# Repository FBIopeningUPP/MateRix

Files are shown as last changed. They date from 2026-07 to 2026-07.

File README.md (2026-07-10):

# MateRix Cyberdeck

MateRix is a 10x10 LED Matrix console built around the ESP32-S3. It runs a standalone C++ operating system for embedded games (Tetris, Snake) and connects to a custom PyQt5 desktop application for live telemetry, screen painting, and device configuration over UART.

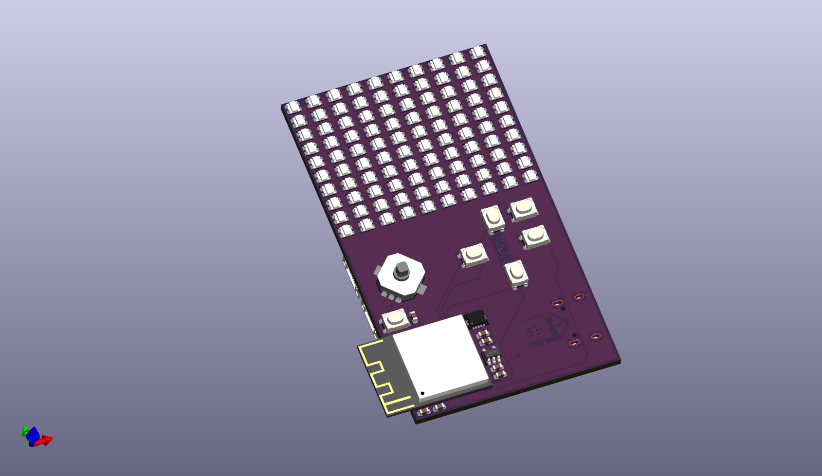
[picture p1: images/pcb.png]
Front PCB Render

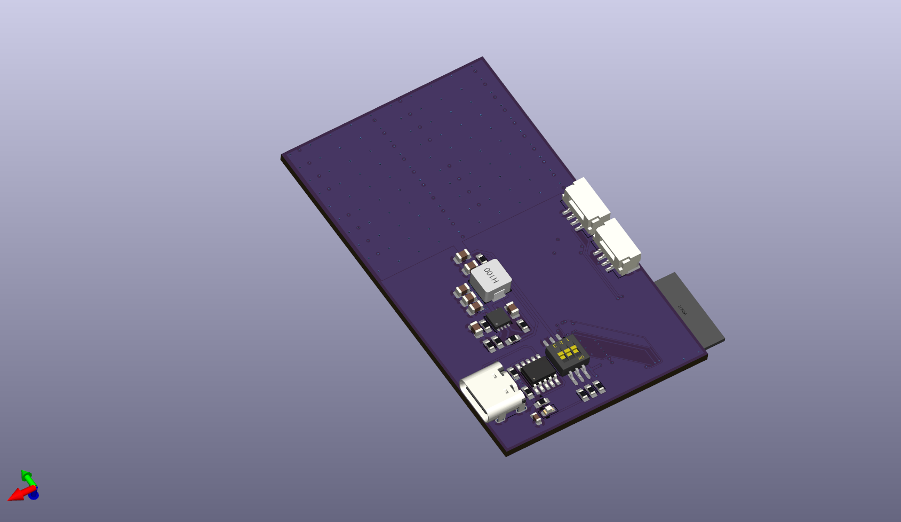
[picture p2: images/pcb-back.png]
Back PCB Render


## Features

* Standalone C++ embedded OS with multitasking state machine
* Playable Tetris and Snake game engines
* Hardware-level Matrix Digital Rain screensaver with idle timeout
* 10x10 WS2812B LED Matrix divided into 4 high-speed hardware quadrants
* Custom Python (PyQt5) desktop studio for live two-way UART communication
* Real-time telemetry broadcasting and remote device configuration
* Open-source hardware and firmware

## Hardware Specifications

* **MCU:** ESP32-S3-Mini
* **Display:** 100x WS2812B LEDs
* **Level Shifter:** 74AHCT125 (3.3V to 5V logic conversion)
* **Inputs:** 4-way D-Pad, 5 Action Buttons (A, B, X, Y, Start)

## Bill of Materials (BoM)

A complete, itemized BOM generated by KiCad can be viewed here: [Production](./production/bom.csv)

## Steps To Reproduce

### Hardware
1. The hardware design files are located in the `hardware/` directory. Send the Gerber files to a manufacturer to produce the PCB.
2. Solder the ESP32-S3-Mini, 74AHCT125, WS2812B LEDs, and tactile buttons.

### Firmware
1. Open the `firmware/` folder in VS Code using the PlatformIO extension.
2. Connect the ESP32-S3 via USB-C and upload the code.

### Software
1. Navigate to the `software/` folder.
2. Run the pre-compiled executable: `software\MateRix_Cyberdeck_Studio.exe`.
3. *(Optional)* To run from source, install dependencies with `pip install pyqt5 pyserial pyautogui` and run `python main.py`.

## Usage of AI

The usage of AI in this project was done with Google Antigravity, which acted as a pair programmer to help debug the C++ firmware, build the Python UI architecture, and verify the hardware pinouts and PCB routing strategies.

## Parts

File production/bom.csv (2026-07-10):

Designator | Footprint | Quantity | Value | LCSC Part #
C201, C203, C205 | 0603 | 3 | 100nF
C202, C204, C206, C207 | 0603 | 4 | 0.1uF
C401 | 0603 | 1 | 1uF
C501, C505 | 0805 | 2 | 100nF
C502, C503, C504 | 0805 | 3 | 1uF
C506, C507 | 0805 | 2 | 22uF
J201, J202 | JST_GH_SM04B-GHS-TB_1x04-1MP_P1.25mm_Horizontal | 2 | Conn_01x04_MountingPin
J401 | USB_C_Receptacle_GCT_USB4105-xx-A_16P_TopMnt_Horizontal | 1 | USB_C_Receptacle_USB2.0_16P
L501 | IND-SMD_L5.2-W5.2_MCW-0530 | 1 | SMMS0530-100M | C181721
LED301, LED302, LED303, LED304, LED305, LED306, LED307, LED308, LED309, LED310, LED311, LED312, LED313, LED314, LED315, LED316, LED317, LED318, LED319, LED320, LED321, LED322, LED323, LED324, LED325, LED326, LED327, LED328, LED329, LED330, LED331, LED332, LED333, LED334, LED335, LED336, LED337, LED338, LED339, LED340, LED341, LED342, LED343, LED344, LED345, LED346, LED347, LED348, LED349, LED350, LED351, LED352, LED353, LED354, LED355, LED356, LED357, LED358, LED359, LED360, LED361, LED362, LED363, LED364, LED365, LED366, LED367, LED368, LED369, LED370, LED371, LED372, LED373, LED374, LED375, LED376, LED377, LED378, LED379, LED380, LED381, LED382, LED383, LED384, LED385, LED386, LED387, LED388, LED389, LED390, LED391, LED392, LED393, LED394, LED395, LED396, LED397, LED398, LED399, LED400 | LED-SMD_4P-L2.0-W2.0-TL_WS2812B-2020 | 100 | WS2812B | C965555
LED401 | 0603 | 1 | LED_0603
R401, R404, R405, R406 | R_0603 | 4 | 10k
R402, R403 | R_0603 | 2 | 1k
R501 | R_0603 | 1 | 100k
R502 | R_0603 | 1 | 330k
R503 | R_0603 | 1 | 20
R504 | R_0603 | 1 | 41.2k
R505 | R_0603 | 1 | 51k
R506 | R_0603 | 1 | 6.98k
SW201 | SW-SMD_SKRHAAE010 | 1 | SKRHAAE010 | C202423
SW202, SW203, SW204, SW205, SW206, SW207 | KEY-SMD_4P-L4.2-W3.2-P2.20-LS4.6 | 6 | SKRPABE010 | C115360
SW401 | SW-SMD_DSHP03TS-S | 1 | DSHP03TS-S | C319051
U202 | DHVQFN-14_L3.0-W2.5-P0.50-BL-EP | 1 | 74AHCT125BQ,115 | C554499
U203 | SOT-23-5_L3.0-W1.7-P0.95-LS2.8-TL | 1 | MIC5219-3.3YM5 | C29613
U401 | SSOP-10-1EP_3.9x4.9mm_P1mm_EP2.1x3.3mm_ThermalVias | 1 | CH224K
U402 | BULETM-SMD_ESP32-S3-MINI-1-N8 | 1 | ESP32-S3-MINI-1-N8 | C2913206
U501 | QFN-8_L3.0-W3.0-P0.65-BL | 1 | MP9943GQ | C51889390

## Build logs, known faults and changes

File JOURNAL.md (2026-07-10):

---
title: MateRix
author: Milind Singh
description: MateRix a esp32 s3 and ws2812b 2020 10x10 matrix display with joystick and some buttons for fun
created_at: 2026-07-20
---

### Total time spent: 
## July 10th -

Today morning i started this simple project with something fun in mind
i choose to build a rgb matrix with joystick and esp32 and some buttons
i wrote the c++ and python code where the mcu is programmed with 2 games and pc mode and screen saver
pc mode u can interact with the python app

the whole project was easy and fast so i completed it fast so i can go to horizons

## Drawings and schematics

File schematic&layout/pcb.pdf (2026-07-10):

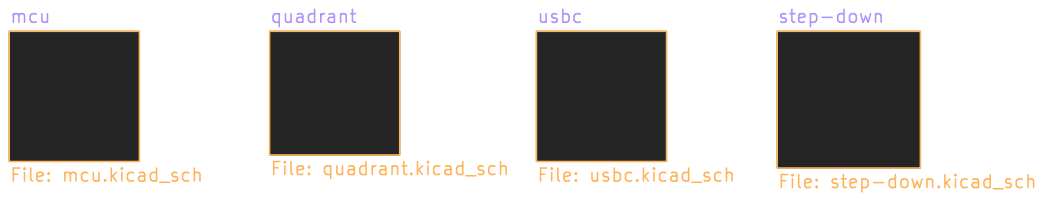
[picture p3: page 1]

step-down File: step-down.kicad_sch

Id: 1/5 Title: File: pcb.kicad_sch Sheet: /

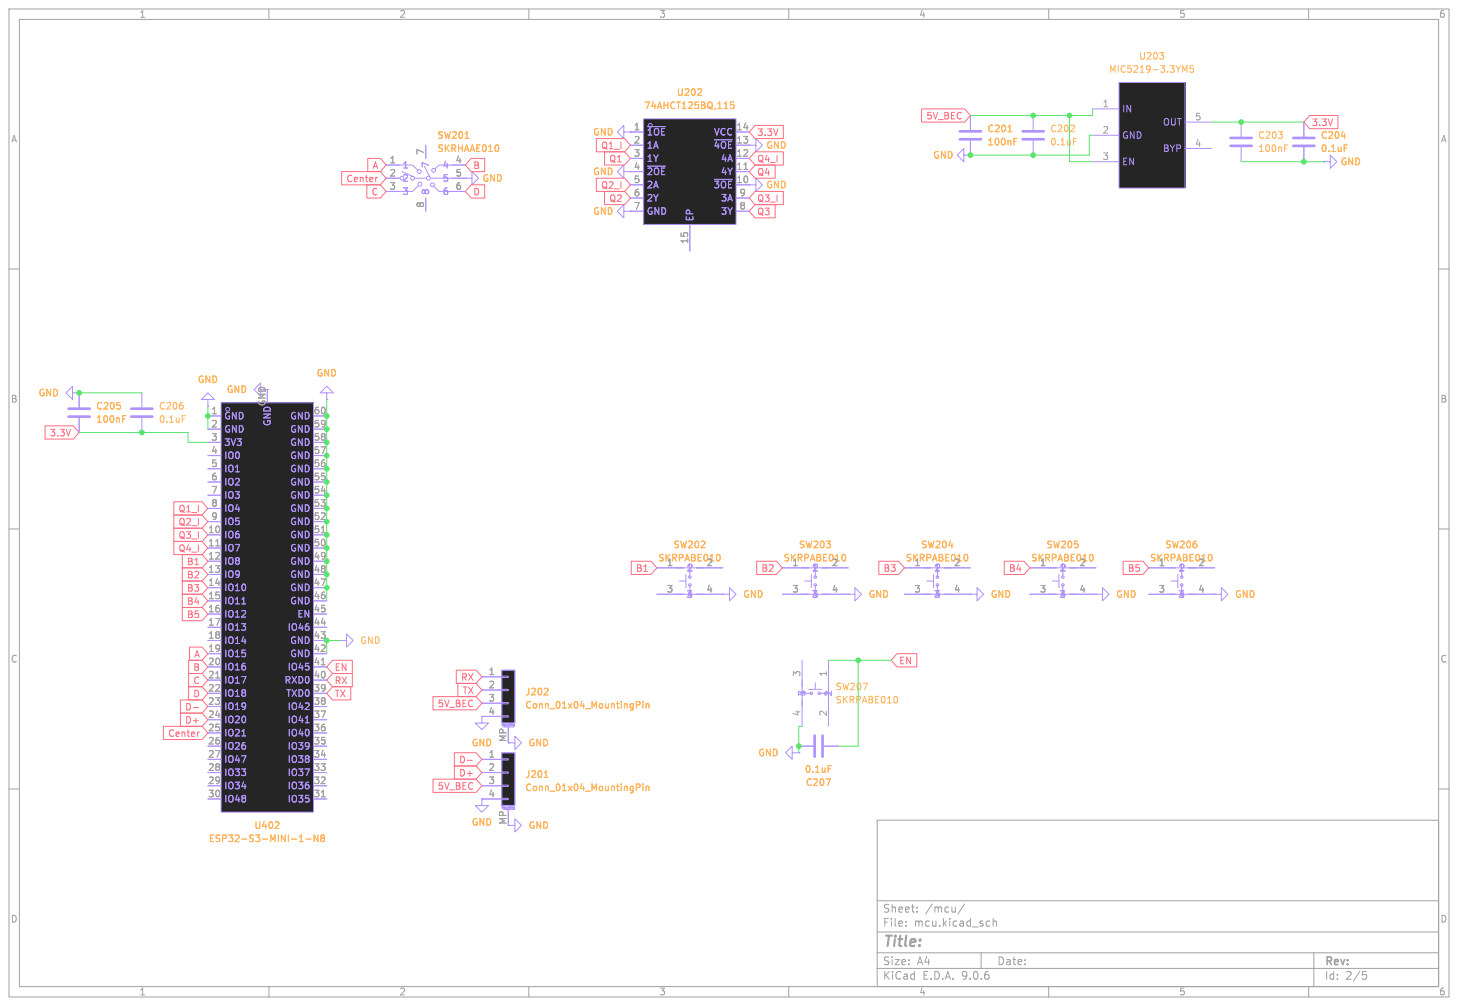
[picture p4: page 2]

Id: 2/5 Title: File: mcu.kicad_sch Sheet: /mcu/ 1

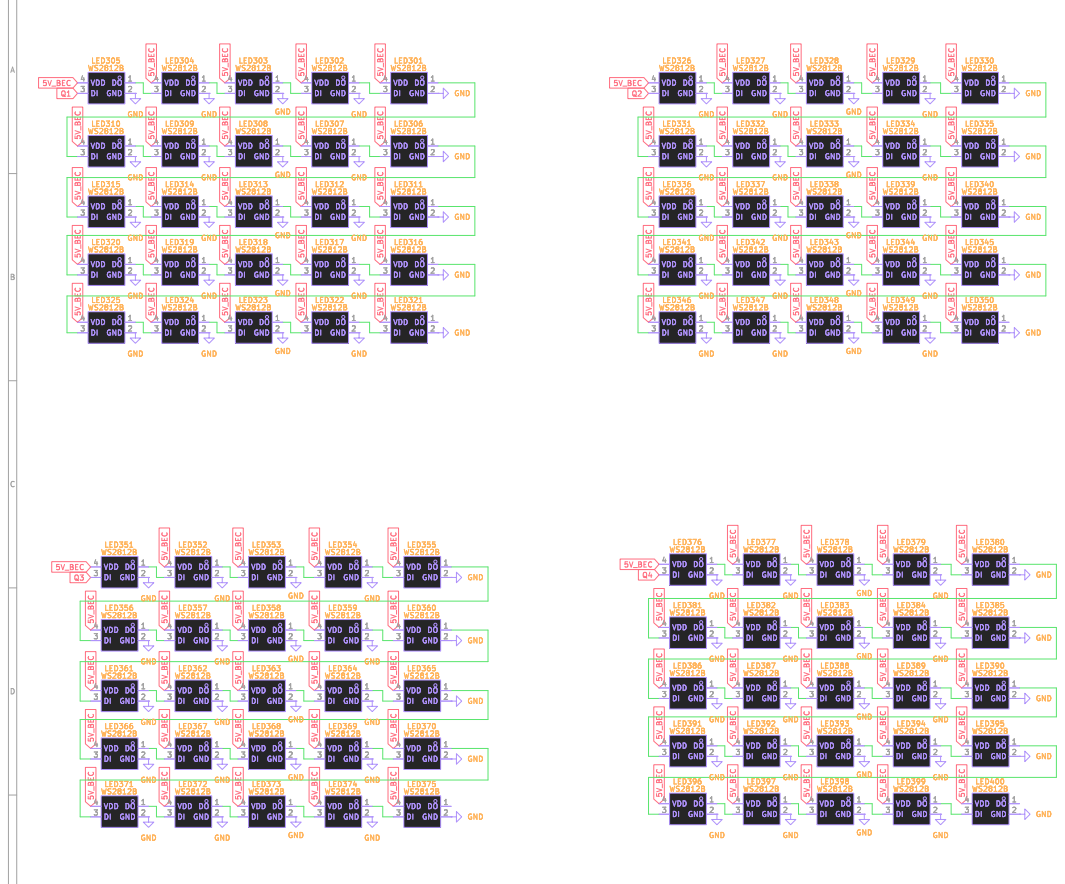
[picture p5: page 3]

LED302 WS2812BDO 1 GND 2 VDD 4 DI 3 GND

LED301 WS2812BDO 1 GND 2 VDD 4 DI 3 GND

LED327 WS2812B DO 1 GND 2 VDD 4 DI 3

DO 1 GND 2 VDD 4 DI 3

LED335 WS2812B DO 1 GND 2 VDD 4 DI 3

LED312 WS2812B DO 1 GND 2 VDD 4 DI 3

LED318 WS2812BDO 1 GND 2 VDD 4 DI 3 GND GND

LED345 WS2812BDO 1 GND 2 VDD 4 DI 3 GND LED344 WS2812BDO 1 GND 2 VDD 4 DI 3

LED344 WS2812B DO 1 GND 2 VDD 4 DI 3

LED359 WS2812B DO 1 GND 2 VDD 4 DI 3

LED376 WS2812B DO 1 GND 2 VDD 4 DI 3

LED350 WS2812BDO 1 GND 2 VDD 4 DI 3 GND
LED348 WS2812BDO 1 GND 2 VDD 4 DI 3 GND

LED322 WS2812B DO 1 GND 2 VDD 4 DI 3

LED347 WS2812B DO 1 GND 2 VDD 4 DI 3

LED352 WS2812B GND

LED380 WS2812BDO 1 GND 2 VDD 4 DI 3 GND

LED359 WS2812BDO 1 GND 2 VDD 4 DI 3 GND

LED390 WS2812BDO 1 GND 2 VDD 4 DI 3 GND

LED385 WS2812BDO 1 GND 2 VDD 4 DI 3 GND

LED389 WS2812B DO 1 GND 2 VDD 4 DI 3

LED395 WS2812B DO 1 GND 2 VDD 4 DI 3

LED373 WS2812B DO 1 GND 2 VDD 4 DI 3

LED375 WS2812BDO 1 GND 2 VDD 4 DI 3 GND

Id: 3/5 Title: File: quadrant.kicad_sch Sheet: /quadrant/

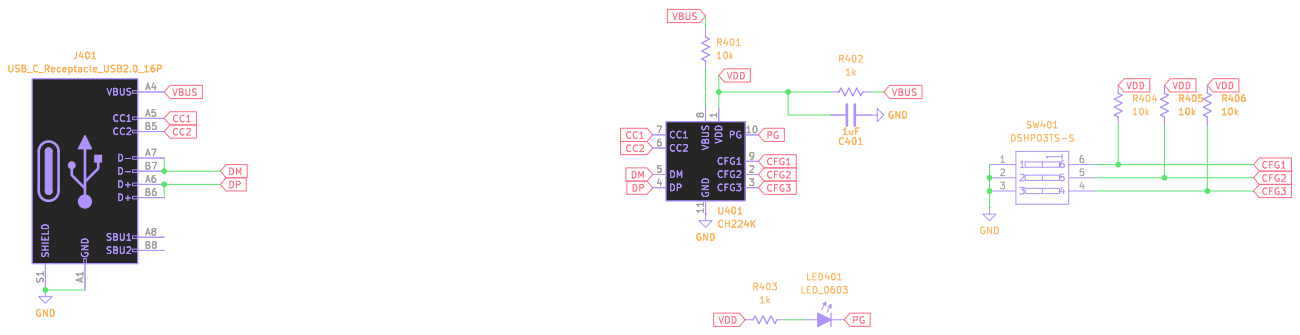
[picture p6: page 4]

Id: 4/5 Title: File: usbc.kicad_sch Sheet: /usbc/ GND

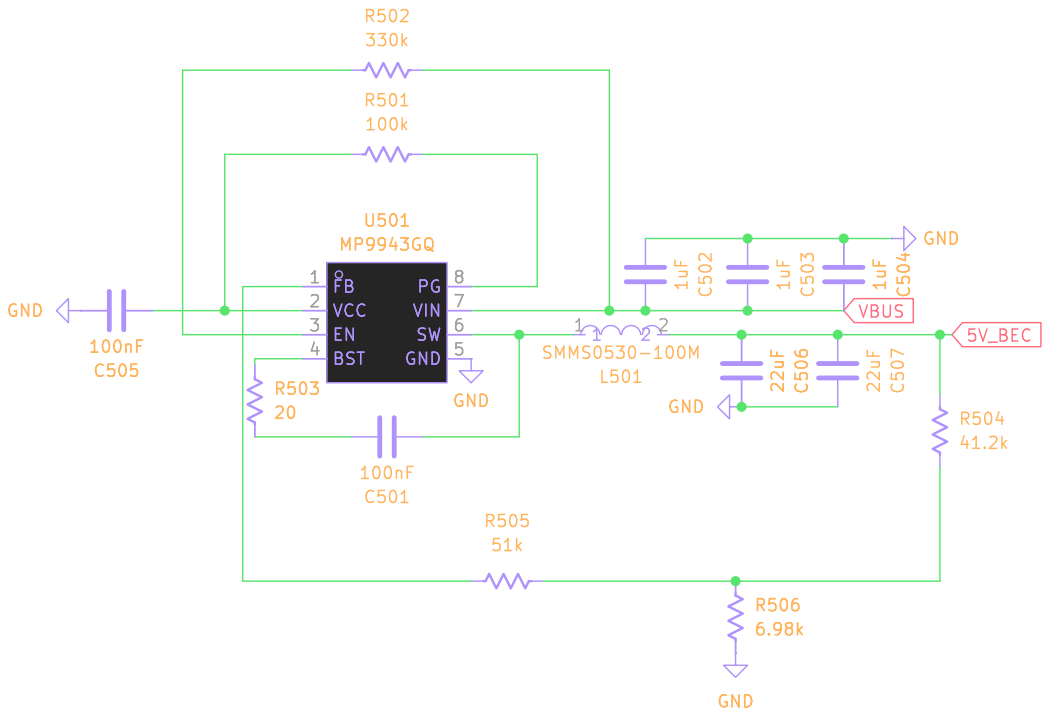
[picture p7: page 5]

Id: 5/5 Title: File: step-down.kicad_sch Sheet: /step-down/

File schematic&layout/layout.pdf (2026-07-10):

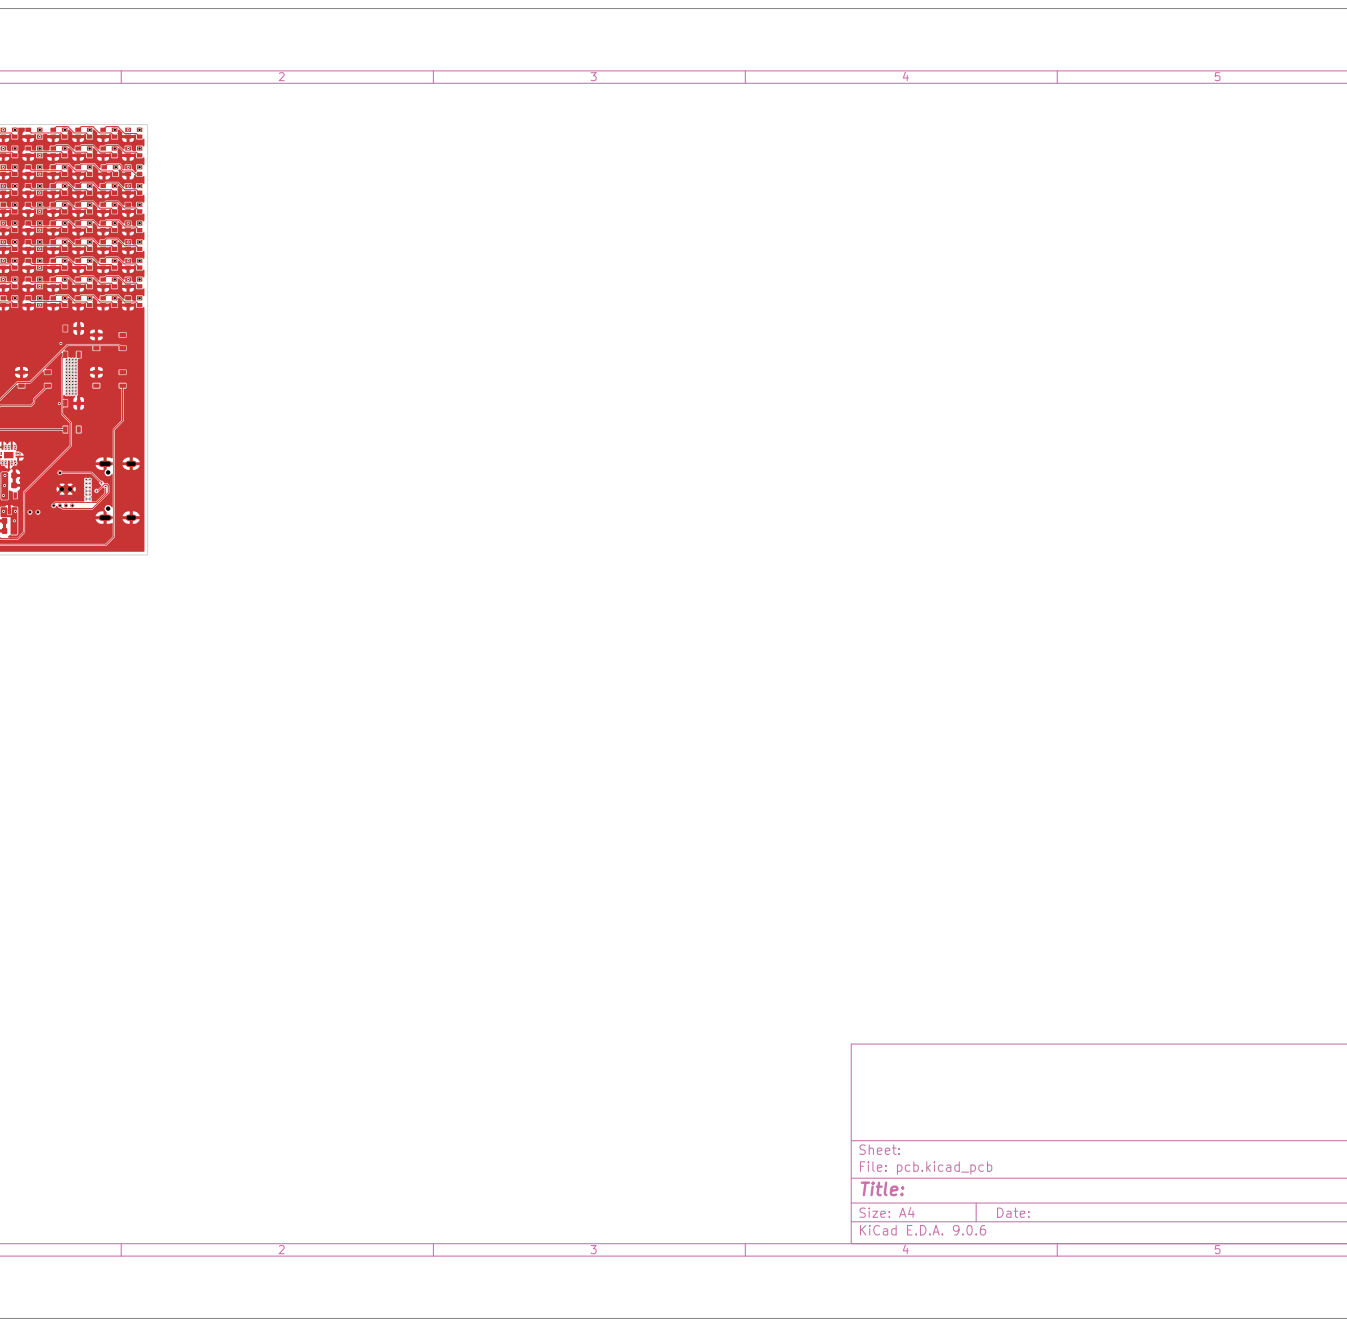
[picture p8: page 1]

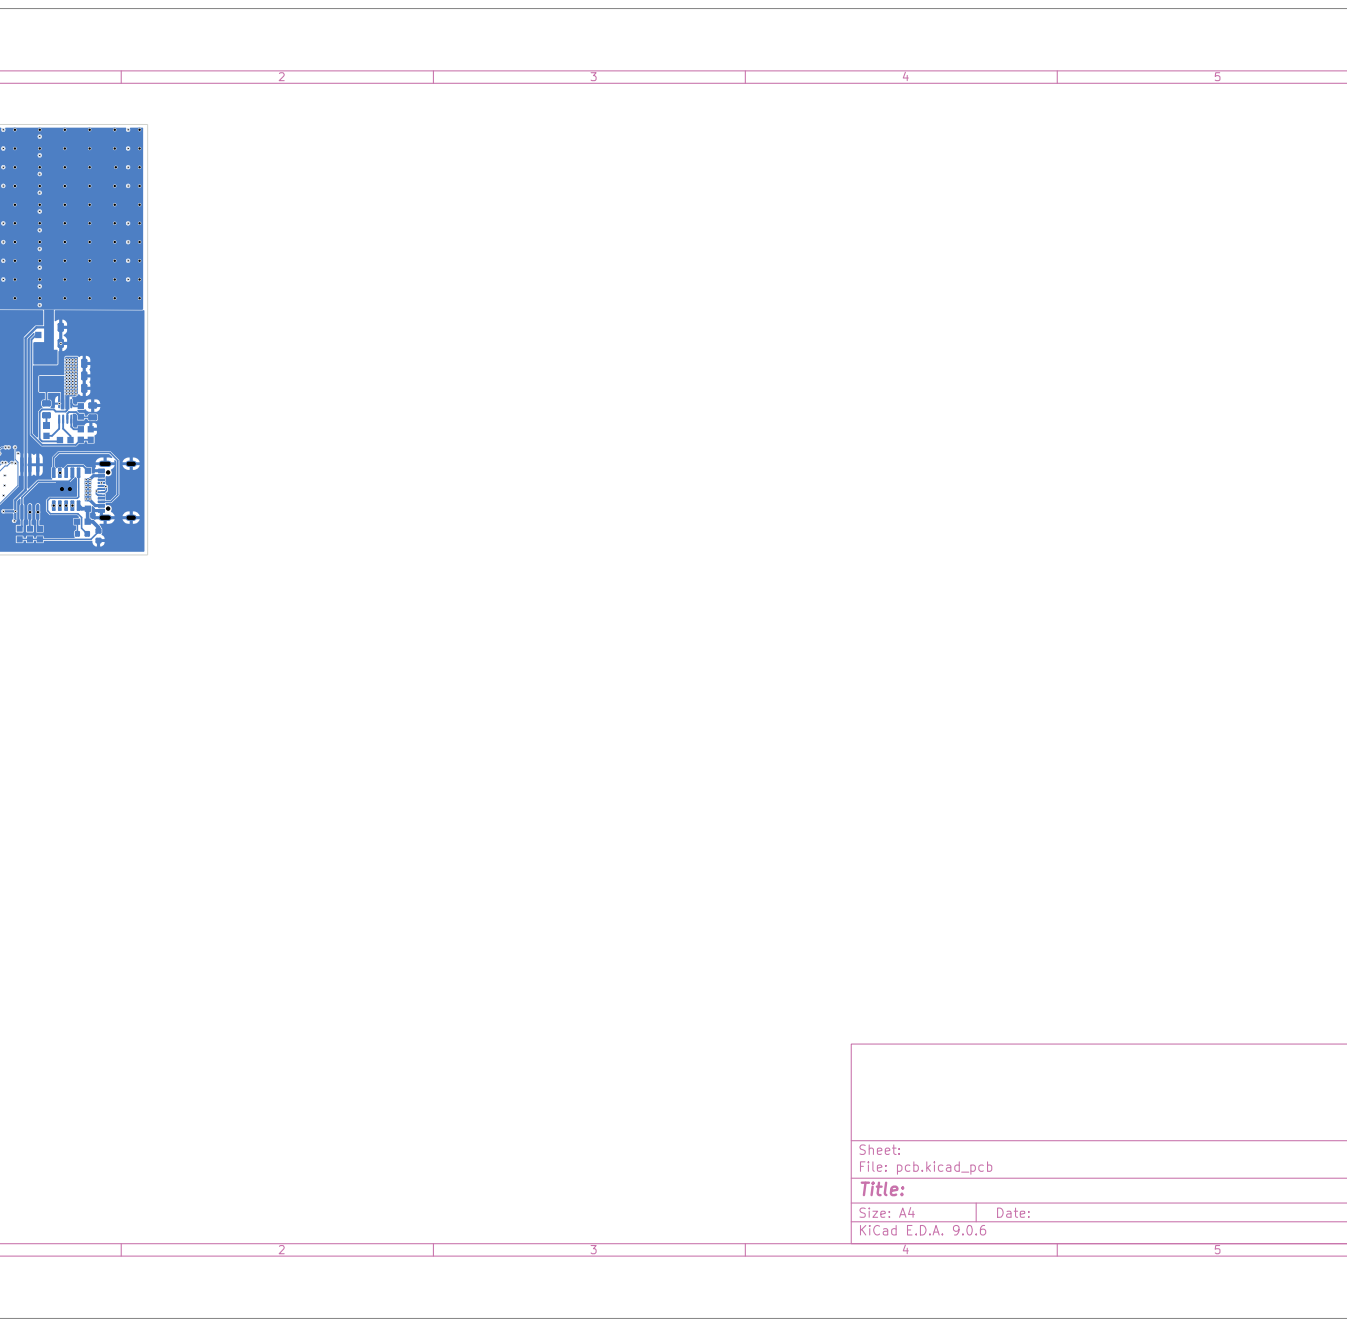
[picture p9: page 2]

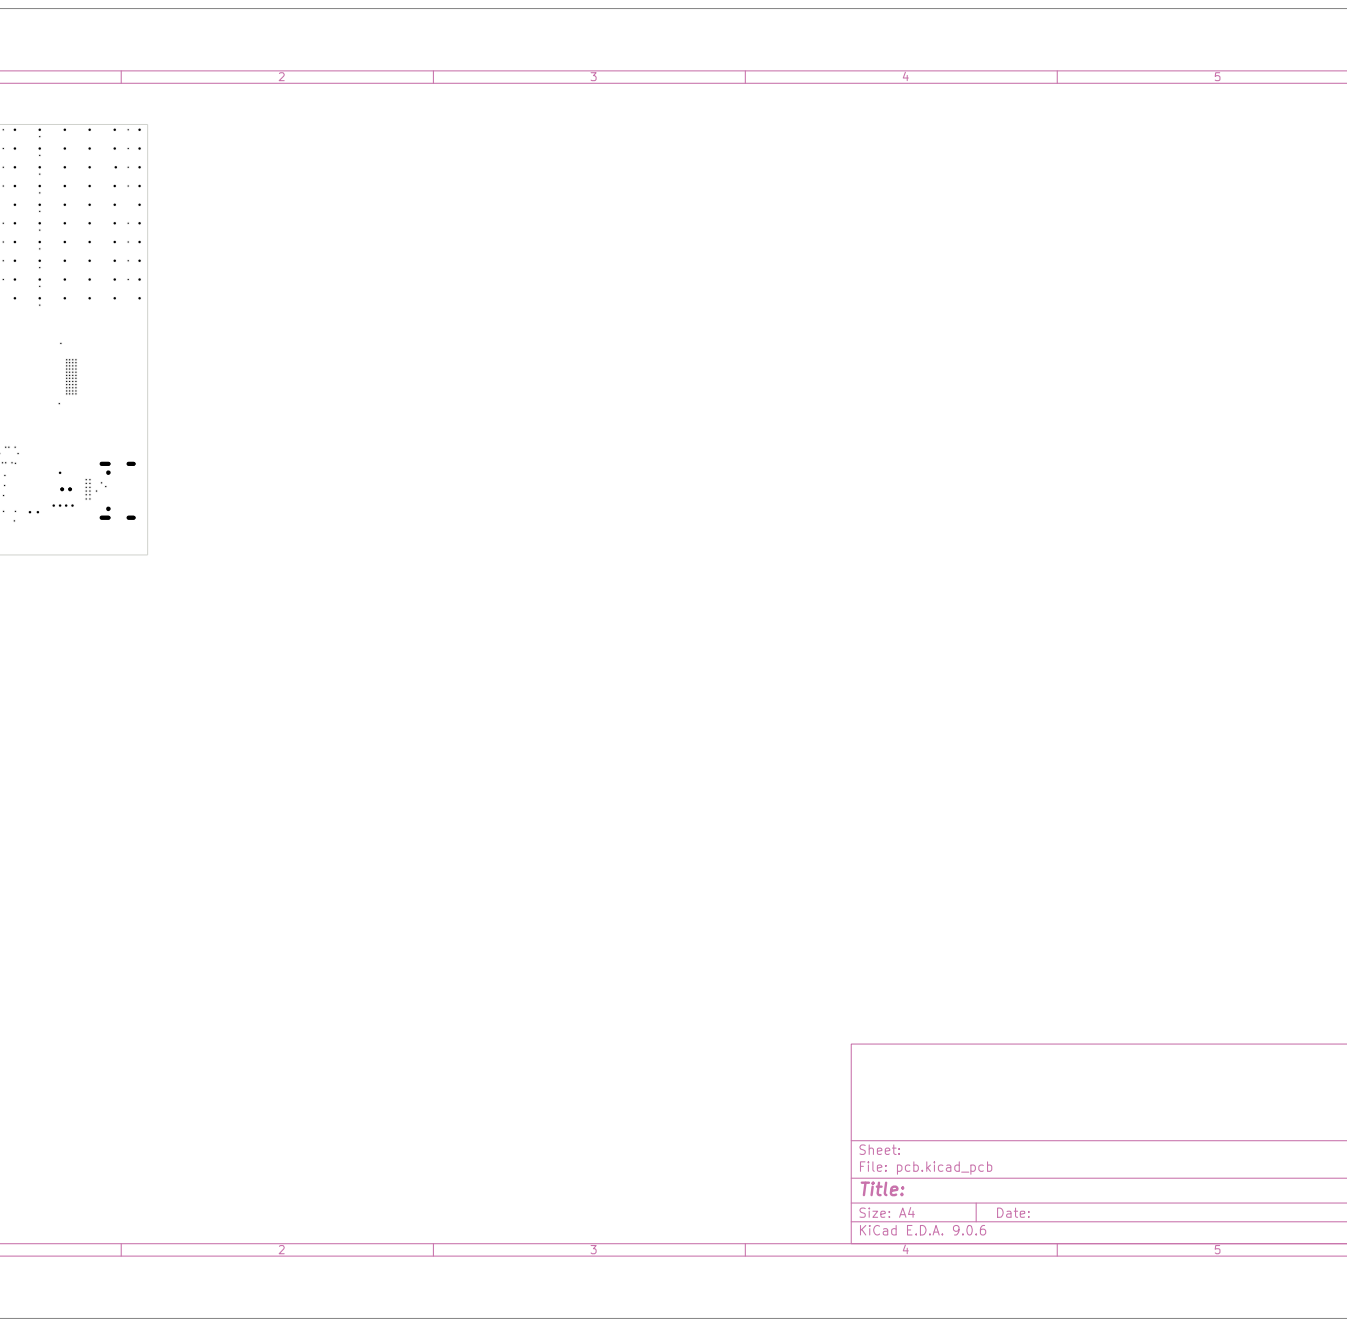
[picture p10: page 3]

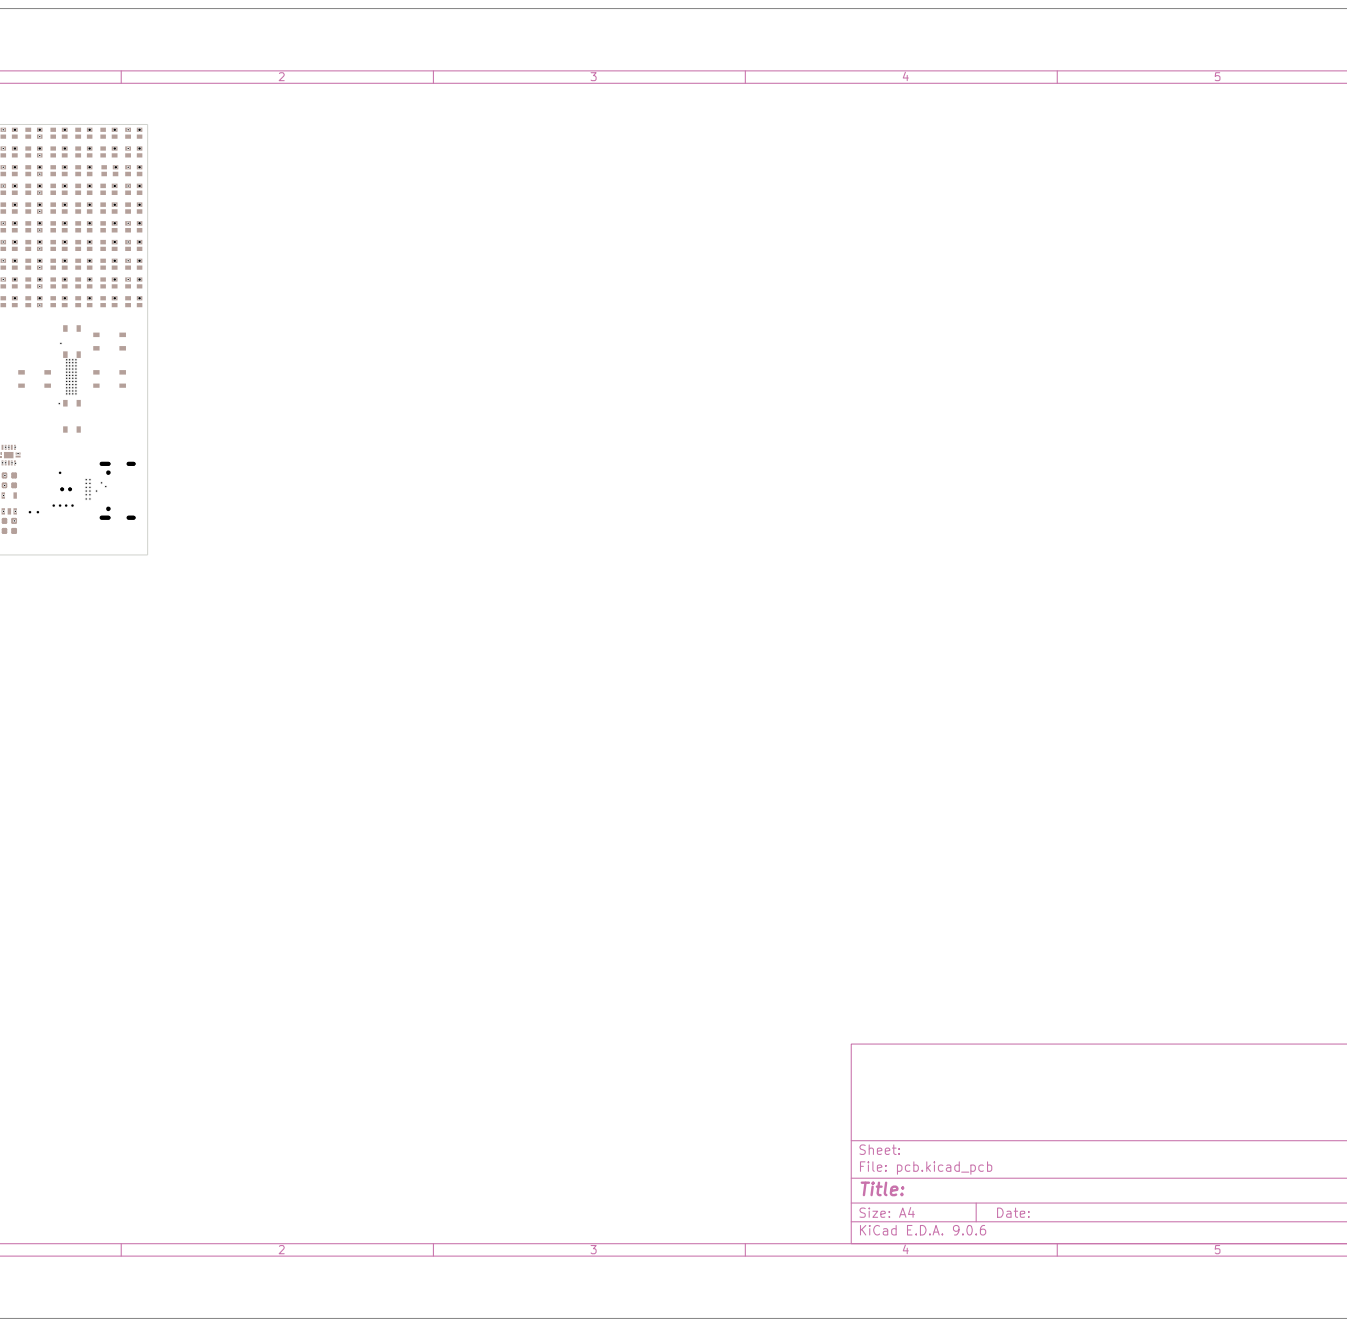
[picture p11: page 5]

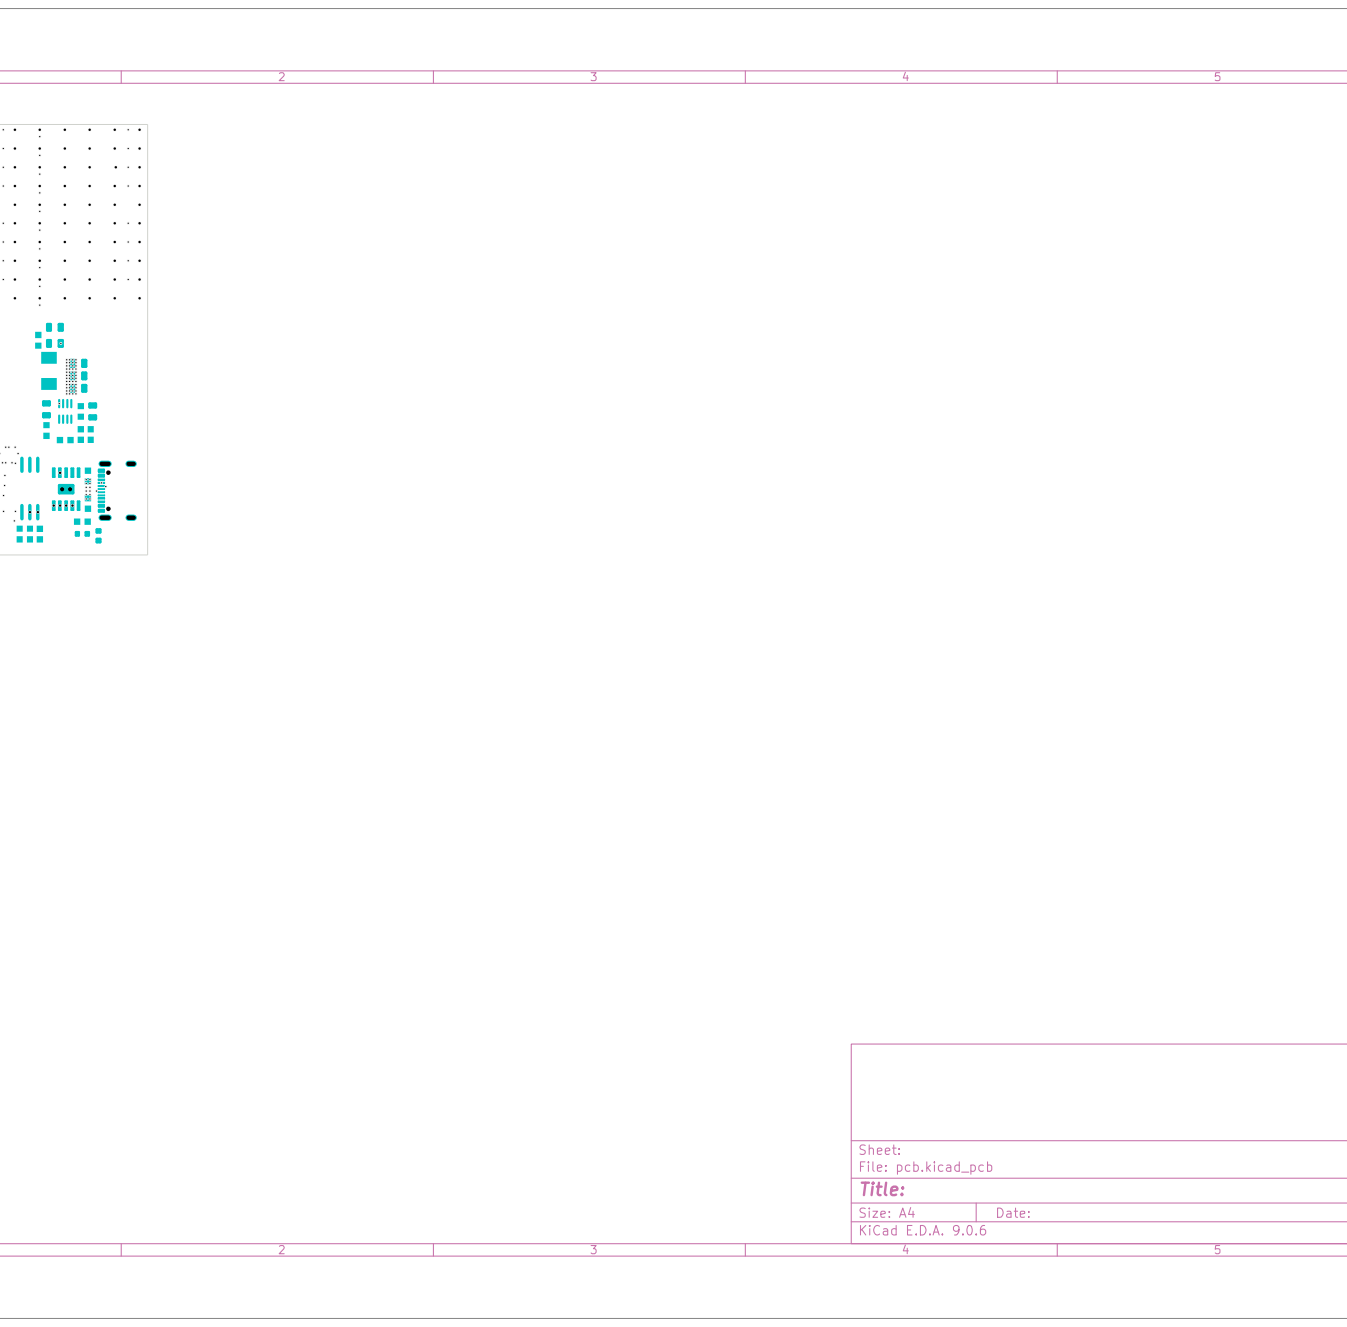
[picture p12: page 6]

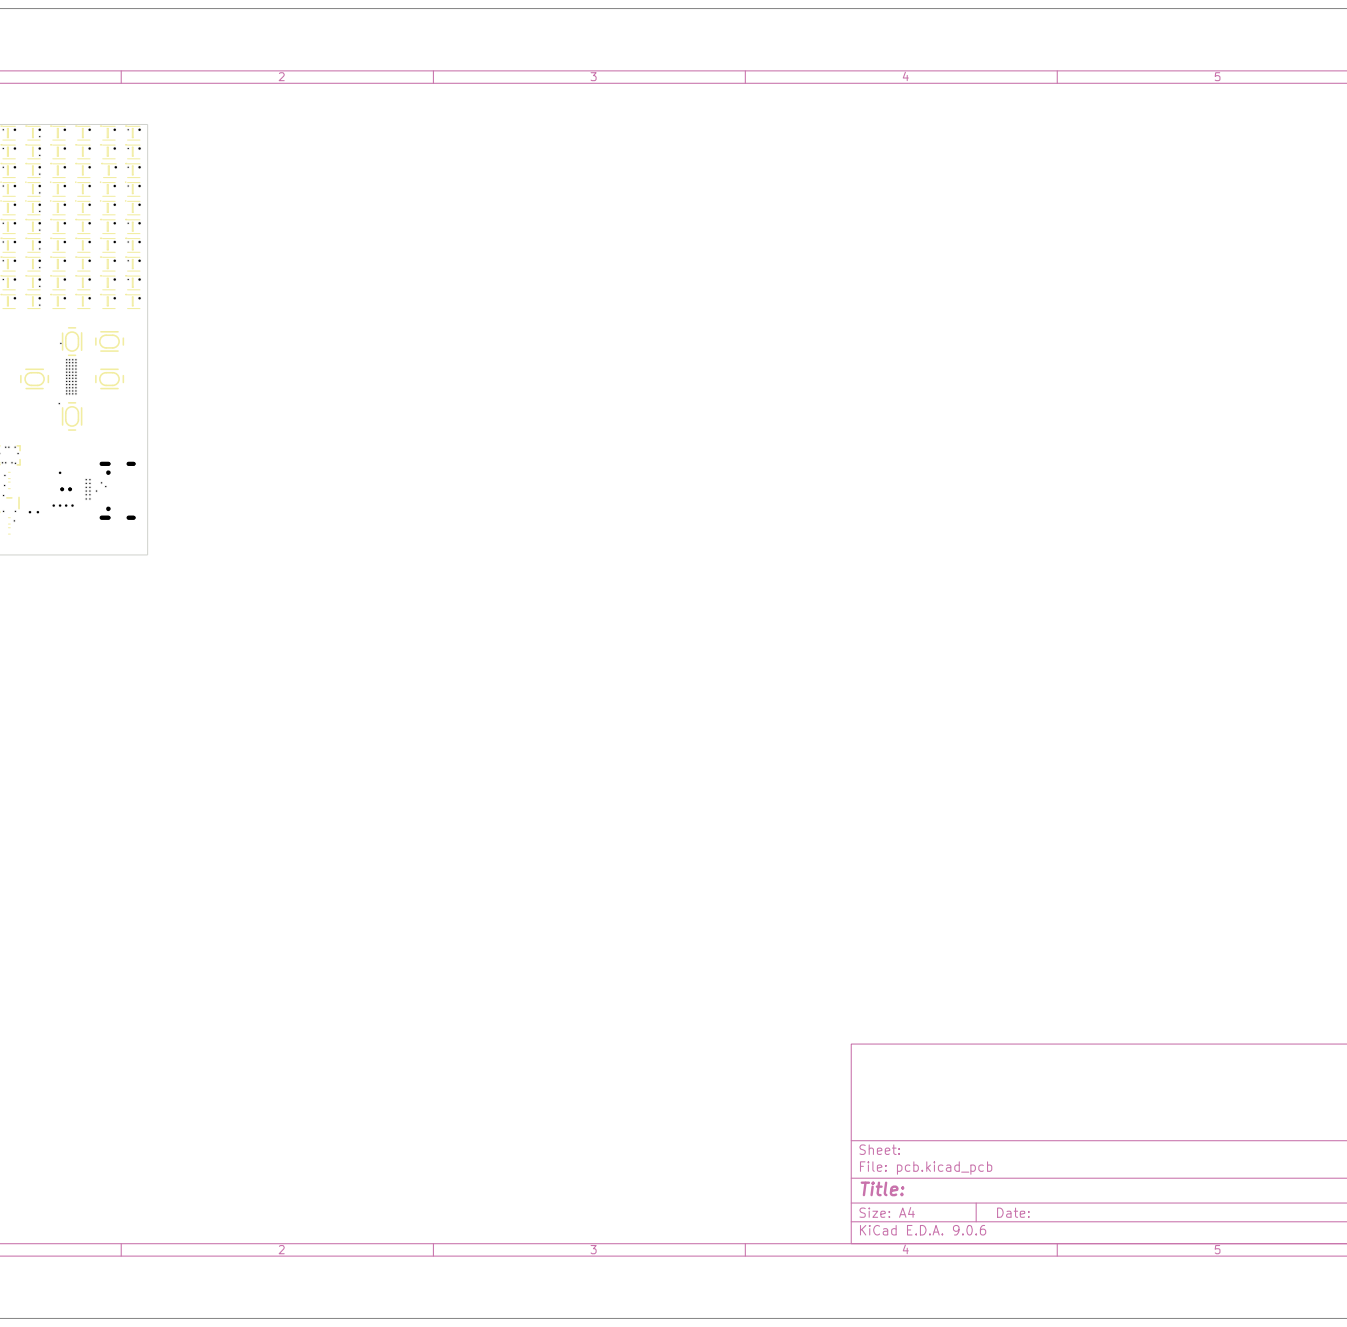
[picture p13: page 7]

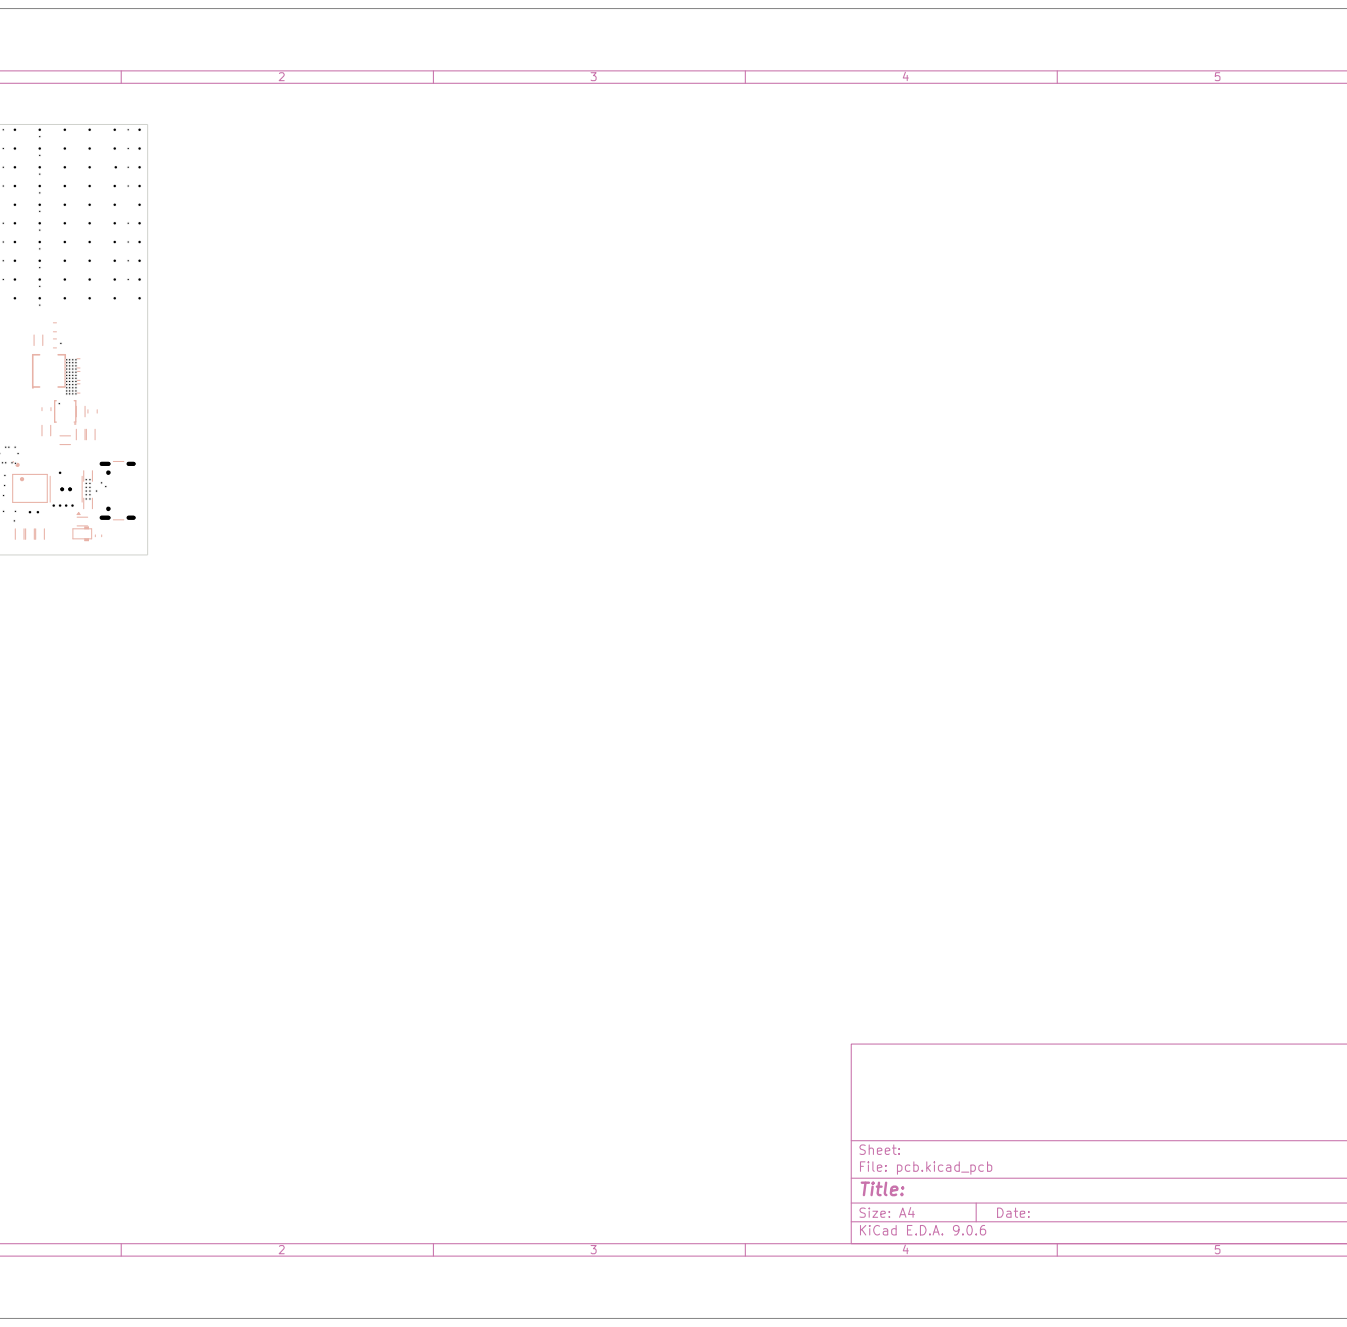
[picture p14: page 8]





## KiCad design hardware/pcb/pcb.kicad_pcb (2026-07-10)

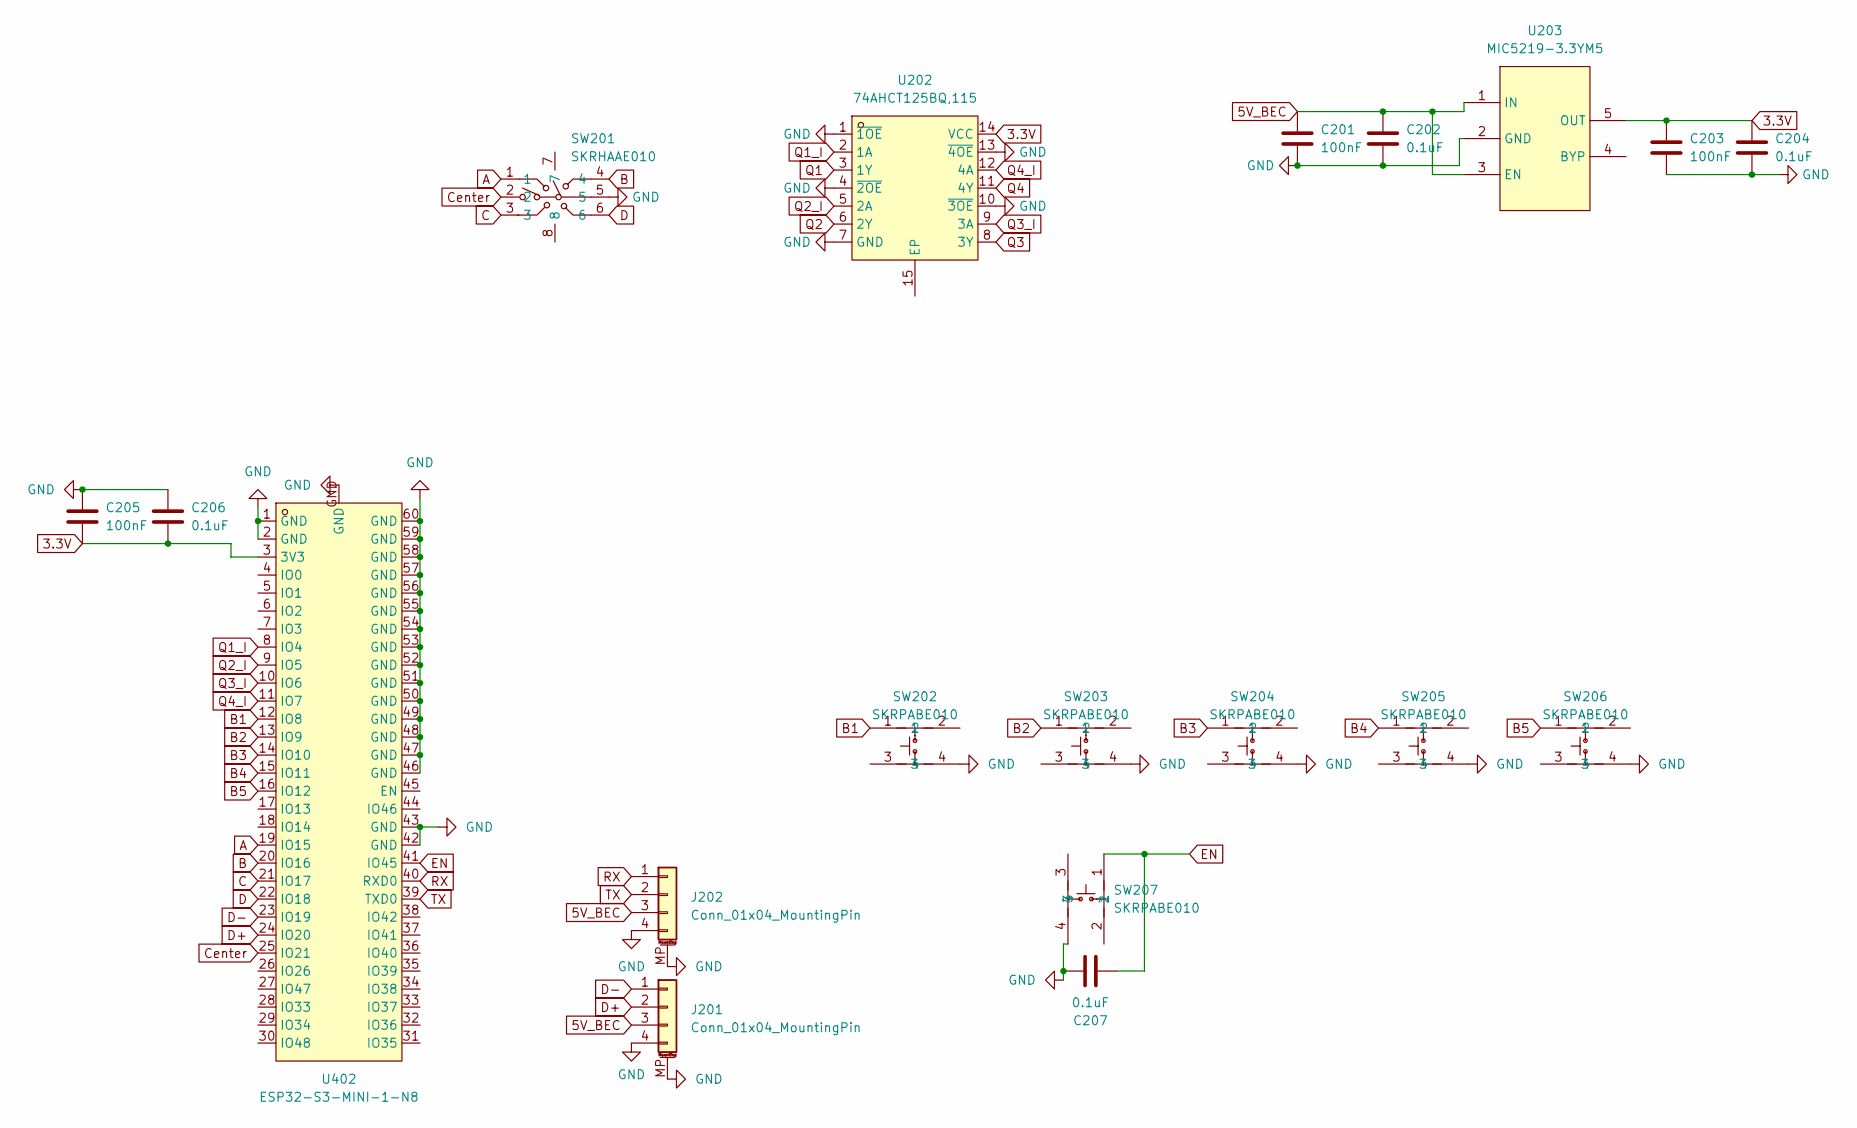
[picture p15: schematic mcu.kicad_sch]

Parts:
C201, C203, C205: 100nF; C_0603_1608Metric
C202, C204, C206, C207: 0.1uF; C_0603_1608Metric
J201, J202: Conn_01x04_MountingPin; JST_GH_SM04B-GHS-TB_1x04-1MP_P1.25mm_Horizontal
SW201: SKRHAAE010; SW-SMD_SKRHAAE010; MPN SKRHAAE010; LCSC Part C202423
SW202, SW203, SW204, SW205, SW206, SW207: SKRPABE010; KEY-SMD_4P-L4.2-W3.2-P2.20-LS4.6; LCSC Part C115360
U202: 74AHCT125BQ,115; DHVQFN-14_L3.0-W2.5-P0.50-BL-EP; MPN 74AHCT125BQ,115; LCSC Part C554499
U203: MIC5219-3.3YM5; SOT-23-5_L3.0-W1.7-P0.95-LS2.8-TL; LCSC Part C29613
U402: ESP32-S3-MINI-1-N8; BULETM-SMD_ESP32-S3-MINI-1-N8; MPN ESP32-S3-MINI-1-N8; LCSC Part C2913206

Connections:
3.3V: C203.1, C204.1, C205.2, C206.2, U202.14 (VCC), U203.5 (OUT), U402.3 (3V3)
5V_BEC: C201.1, C202.1, J201.3, J202.3, U203.1 (IN), U203.3 (EN); also elsewhere on the board
A: SW201.1, U402.19 (IO15)
B: SW201.4, U402.20 (IO16)
B1: SW202.1, U402.12 (IO8)
B2: SW203.1, U402.13 (IO9)
B3: SW204.1, U402.14 (IO10)
B4: SW205.1, U402.15 (IO11)
B5: SW206.1, U402.16 (IO12)
C: SW201.3, U402.21 (IO17)
Center: SW201.2, U402.25 (IO21)
D: SW201.6, U402.22 (IO18)
D+: J201.2, U402.24 (IO20)
D-: J201.1, U402.23 (IO19)
EN: C207.2, SW207.1, U402.41 (IO45)
GND: C201.2, C202.2, C203.2, C204.2, C205.1, C206.1, C207.1, J201.4, J201.MP (MountPin), J202.4, J202.MP (MountPin), SW201.5, SW202.4, SW203.4, SW204.4, SW205.4, SW206.4, SW207.4, U202.1 (~1OE), U202.4 (~2OE), U202.7 (GND), U202.10 (~3OE), U202.13 (~4OE), U203.2 (GND), U402.1 (GND), U402.2 (GND), U402.42 (GND), U402.43 (GND), U402.46 (GND), U402.47 (GND), U402.48 (GND), U402.49 (GND), U402.50 (GND), U402.51 (GND), U402.52 (GND), U402.53 (GND), U402.54 (GND), U402.55 (GND), U402.56 (GND), U402.57 (GND), U402.58 (GND), U402.59 (GND), U402.60 (GND), U402.GND; also elsewhere on the board
Q1: U202.3 (1Y); also elsewhere on the board
Q1_I: U202.2 (1A), U402.8 (IO4)
Q2: U202.6 (2Y); also elsewhere on the board
Q2_I: U202.5 (2A), U402.9 (IO5)
Q3: U202.8 (3Y); also elsewhere on the board
Q3_I: U202.9 (3A), U402.10 (IO6)
Q4: U202.11 (4Y); also elsewhere on the board
Q4_I: U202.12 (4A), U402.11 (IO7)
RX: J202.1, U402.40 (RXD0)
TX: J202.2, U402.39 (TXD0)

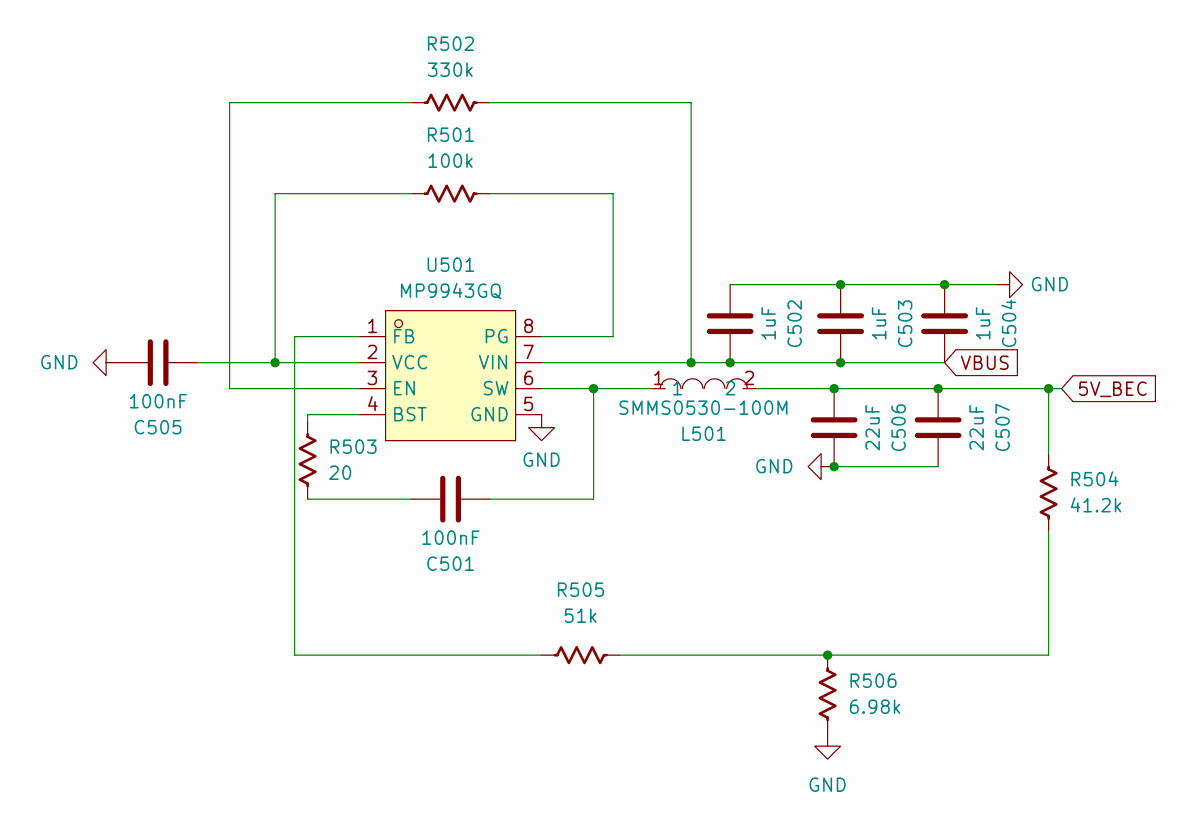
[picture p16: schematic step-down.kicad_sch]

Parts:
C501, C505: 100nF; C_0805_2012Metric
C502, C503, C504: 1uF; C_0805_2012Metric
C506, C507: 22uF; C_0805_2012Metric
L501: SMMS0530-100M; IND-SMD_L5.2-W5.2_MCW-0530; MPN SMMS0530-100M; LCSC Part C181721
R501: 100k; R_0603
R502: 330k; R_0603
R503: 20; R_0603
R504: 41.2k; R_0603
R505: 51k; R_0603
R506: 6.98k; R_0603
U501: MP9943GQ; QFN-8_L3.0-W3.0-P0.65-BL; MPN MP9943GQ(TOKMAS); LCSC Part C51889390

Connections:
5V_BEC: C506.2, C507.2, L501.2, R504.2; also elsewhere on the board
GND: C502.2, C503.2, C504.2, C505.1, C506.1, C507.1, R506.2, U501.5 (GND); also elsewhere on the board
unnamed: C501.1, R503.2
unnamed: R504.1, R505.1, R506.1
unnamed: R503.1, U501.4 (BST)
unnamed: R502.2, U501.3 (EN)
unnamed: R505.2, U501.1 (FB)
unnamed: R501.1, U501.8 (PG)
unnamed: C501.2, L501.1, U501.6 (SW)
unnamed: C505.2, R501.2, U501.2 (VCC)
VBUS: C502.1, C503.1, C504.1, R502.1, U501.7 (VIN); also elsewhere on the board

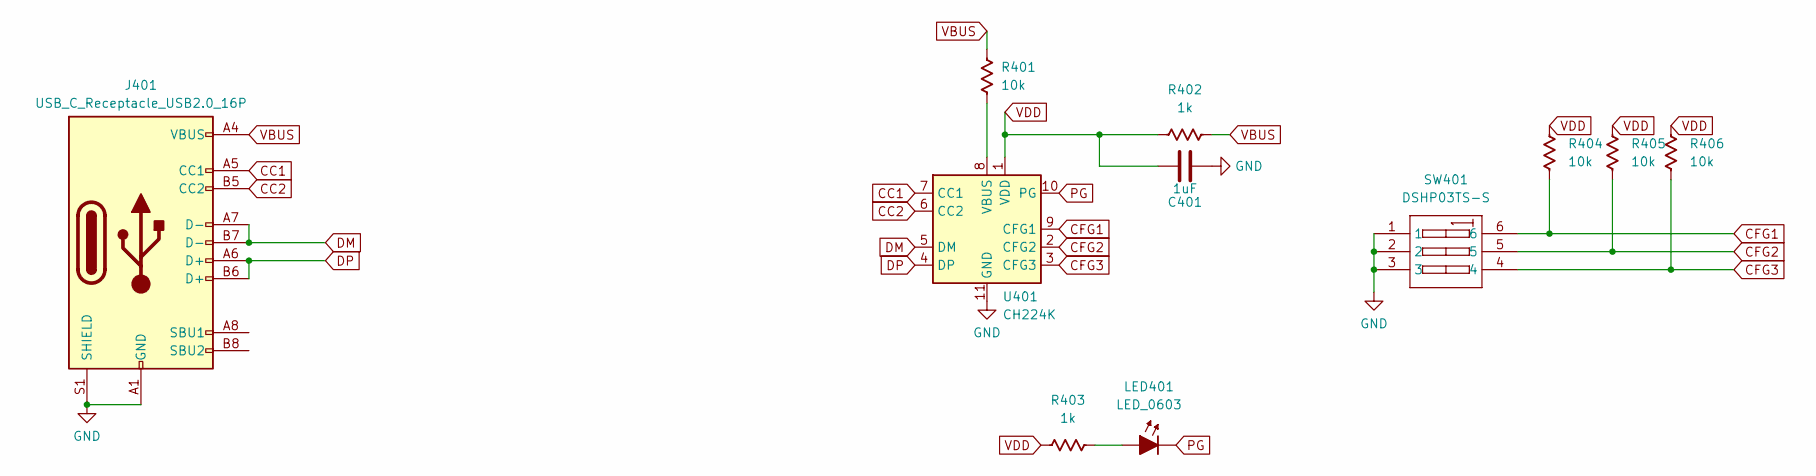
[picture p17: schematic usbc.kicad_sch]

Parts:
C401: 1uF; C_0603_1608Metric
J401: USB_C_Receptacle_USB2.0_16P; USB_C_Receptacle_GCT_USB4105-xx-A_16P_TopMnt_Horizontal
LED401: LED_0603; LED_0603_1608Metric
R401, R404, R405, R406: 10k; R_0603
R402, R403: 1k; R_0603
SW401: DSHP03TS-S; SW-SMD_DSHP03TS-S; MPN DSHP03TS-S; LCSC Part C319051
U401: CH224K; SSOP-10-1EP_3.9x4.9mm_P1mm_EP2.1x3.3mm_ThermalVias

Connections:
CC1: J401.A5 (CC1), U401.7 (CC1)
CC2: J401.B5 (CC2), U401.6 (CC2)
CFG1: R404.1, SW401.6, U401.9 (CFG1)
CFG2: R405.1, SW401.5, U401.2 (CFG2)
CFG3: R406.1, SW401.4, U401.3 (CFG3)
DM: J401.A7 (D-), J401.B7 (D-), U401.5 (DM)
DP: J401.A6 (D+), J401.B6 (D+), U401.4 (DP)
GND: C401.2, J401.A1 (GND), J401.A12 (GND), J401.B1 (GND), J401.B12 (GND), J401.S1 (SHIELD), SW401.1, SW401.2, SW401.3, U401.11 (GND); also elsewhere on the board
unnamed: LED401.2 (A), R403.2
unnamed: R401.2, U401.8 (VBUS)
PG: LED401.1 (K), U401.10 (PG)
VBUS: J401.A4 (VBUS), J401.A9 (VBUS), J401.B4 (VBUS), J401.B9 (VBUS), R401.1, R402.2; also elsewhere on the board
VDD: C401.1, R402.1, R403.1, R404.2, R405.2, R406.2, U401.1 (VDD)

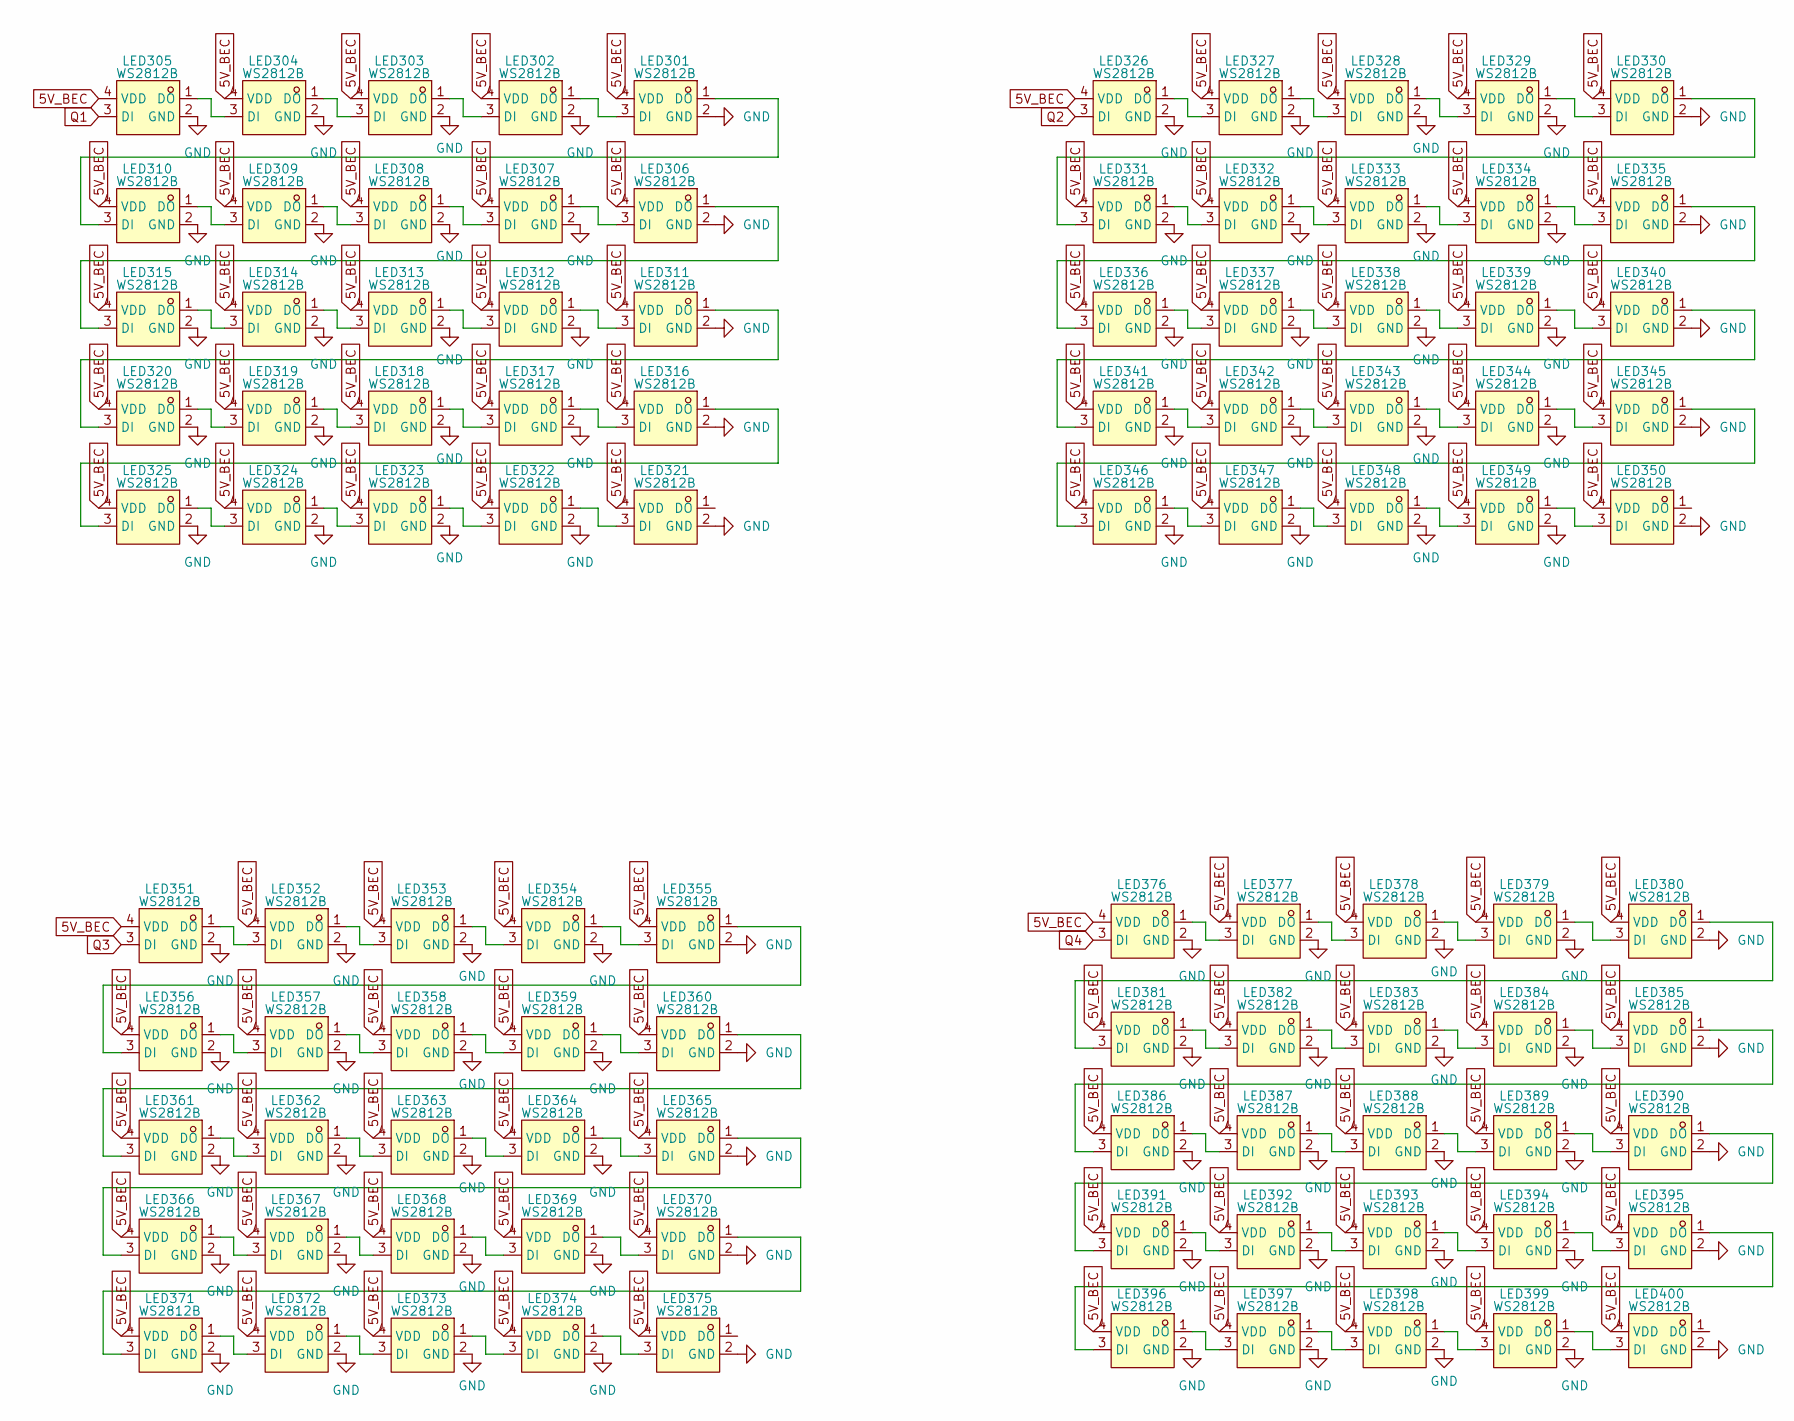
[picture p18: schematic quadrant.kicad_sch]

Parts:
LED301, LED302, LED303, LED304, LED305, LED306, LED307, LED308, LED309, LED310, LED311, LED312, LED313, LED314, LED315, LED316, LED317, LED318, LED319, LED320, LED321, LED322, LED323, LED324, LED325, LED326, LED327, LED328, LED329, LED330, LED331, LED332, LED333, LED334, LED335, LED336, LED337, LED338, LED339, LED340, LED341, LED342, LED343, LED344, LED345, LED346, LED347, LED348, LED349, LED350, LED351, LED352, LED353, LED354, LED355, LED356, LED357, LED358, LED359, LED360, LED361, LED362, LED363, LED364, LED365, LED366, LED367, LED368, LED369, LED370, LED371, LED372, LED373, LED374, LED375, LED376, LED377, LED378, LED379, LED380, LED381, LED382, LED383, LED384, LED385, LED386, LED387, LED388, LED389, LED390, LED391, LED392, LED393, LED394, LED395, LED396, LED397, LED398, LED399, LED400: WS2812B; LED-SMD_4P-L2.0-W2.0-TL_WS2812B-2020; MPN WS2812B-2020; LCSC Part C965555

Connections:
5V_BEC: LED301.4 (VDD), LED302.4 (VDD), LED303.4 (VDD), LED304.4 (VDD), LED305.4 (VDD), LED306.4 (VDD), LED307.4 (VDD), LED308.4 (VDD), LED309.4 (VDD), LED310.4 (VDD), LED311.4 (VDD), LED312.4 (VDD), LED313.4 (VDD), LED314.4 (VDD), LED315.4 (VDD), LED316.4 (VDD), LED317.4 (VDD), LED318.4 (VDD), LED319.4 (VDD), LED320.4 (VDD), LED321.4 (VDD), LED322.4 (VDD), LED323.4 (VDD), LED324.4 (VDD), LED325.4 (VDD), LED326.4 (VDD), LED327.4 (VDD), LED328.4 (VDD), LED329.4 (VDD), LED330.4 (VDD), LED331.4 (VDD), LED332.4 (VDD), LED333.4 (VDD), LED334.4 (VDD), LED335.4 (VDD), LED336.4 (VDD), LED337.4 (VDD), LED338.4 (VDD), LED339.4 (VDD), LED340.4 (VDD), LED341.4 (VDD), LED342.4 (VDD), LED343.4 (VDD), LED344.4 (VDD), LED345.4 (VDD), LED346.4 (VDD), LED347.4 (VDD), LED348.4 (VDD), LED349.4 (VDD), LED350.4 (VDD), LED351.4 (VDD), LED352.4 (VDD), LED353.4 (VDD), LED354.4 (VDD), LED355.4 (VDD), LED356.4 (VDD), LED357.4 (VDD), LED358.4 (VDD), LED359.4 (VDD), LED360.4 (VDD), LED361.4 (VDD), LED362.4 (VDD), LED363.4 (VDD), LED364.4 (VDD), LED365.4 (VDD), LED366.4 (VDD), LED367.4 (VDD), LED368.4 (VDD), LED369.4 (VDD), LED370.4 (VDD), LED371.4 (VDD), LED372.4 (VDD), LED373.4 (VDD), LED374.4 (VDD), LED375.4 (VDD), LED376.4 (VDD), LED377.4 (VDD), LED378.4 (VDD), LED379.4 (VDD), LED380.4 (VDD), LED381.4 (VDD), LED382.4 (VDD), LED383.4 (VDD), LED384.4 (VDD), LED385.4 (VDD), LED386.4 (VDD), LED387.4 (VDD), LED388.4 (VDD), LED389.4 (VDD), LED390.4 (VDD), LED391.4 (VDD), LED392.4 (VDD), LED393.4 (VDD), LED394.4 (VDD), LED395.4 (VDD), LED396.4 (VDD), LED397.4 (VDD), LED398.4 (VDD), LED399.4 (VDD), LED400.4 (VDD); also elsewhere on the board
GND: LED301.2 (GND), LED302.2 (GND), LED303.2 (GND), LED304.2 (GND), LED305.2 (GND), LED306.2 (GND), LED307.2 (GND), LED308.2 (GND), LED309.2 (GND), LED310.2 (GND), LED311.2 (GND), LED312.2 (GND), LED313.2 (GND), LED314.2 (GND), LED315.2 (GND), LED316.2 (GND), LED317.2 (GND), LED318.2 (GND), LED319.2 (GND), LED320.2 (GND), LED321.2 (GND), LED322.2 (GND), LED323.2 (GND), LED324.2 (GND), LED325.2 (GND), LED326.2 (GND), LED327.2 (GND), LED328.2 (GND), LED329.2 (GND), LED330.2 (GND), LED331.2 (GND), LED332.2 (GND), LED333.2 (GND), LED334.2 (GND), LED335.2 (GND), LED336.2 (GND), LED337.2 (GND), LED338.2 (GND), LED339.2 (GND), LED340.2 (GND), LED341.2 (GND), LED342.2 (GND), LED343.2 (GND), LED344.2 (GND), LED345.2 (GND), LED346.2 (GND), LED347.2 (GND), LED348.2 (GND), LED349.2 (GND), LED350.2 (GND), LED351.2 (GND), LED352.2 (GND), LED353.2 (GND), LED354.2 (GND), LED355.2 (GND), LED356.2 (GND), LED357.2 (GND), LED358.2 (GND), LED359.2 (GND), LED360.2 (GND), LED361.2 (GND), LED362.2 (GND), LED363.2 (GND), LED364.2 (GND), LED365.2 (GND), LED366.2 (GND), LED367.2 (GND), LED368.2 (GND), LED369.2 (GND), LED370.2 (GND), LED371.2 (GND), LED372.2 (GND), LED373.2 (GND), LED374.2 (GND), LED375.2 (GND), LED376.2 (GND), LED377.2 (GND), LED378.2 (GND), LED379.2 (GND), LED380.2 (GND), LED381.2 (GND), LED382.2 (GND), LED383.2 (GND), LED384.2 (GND), LED385.2 (GND), LED386.2 (GND), LED387.2 (GND), LED388.2 (GND), LED389.2 (GND), LED390.2 (GND), LED391.2 (GND), LED392.2 (GND), LED393.2 (GND), LED394.2 (GND), LED395.2 (GND), LED396.2 (GND), LED397.2 (GND), LED398.2 (GND), LED399.2 (GND), LED400.2 (GND); also elsewhere on the board
unnamed: LED301.3 (DI), LED302.1 (DO)
unnamed: LED301.1 (DO), LED310.3 (DI)
unnamed: LED302.3 (DI), LED303.1 (DO)
unnamed: LED303.3 (DI), LED304.1 (DO)
unnamed: LED304.3 (DI), LED305.1 (DO)
unnamed: LED306.3 (DI), LED307.1 (DO)
unnamed: LED306.1 (DO), LED315.3 (DI)
unnamed: LED307.3 (DI), LED308.1 (DO)
unnamed: LED308.3 (DI), LED309.1 (DO)
unnamed: LED309.3 (DI), LED310.1 (DO)
unnamed: LED311.3 (DI), LED312.1 (DO)
unnamed: LED311.1 (DO), LED320.3 (DI)
unnamed: LED312.3 (DI), LED313.1 (DO)
unnamed: LED313.3 (DI), LED314.1 (DO)
unnamed: LED314.3 (DI), LED315.1 (DO)
unnamed: LED316.3 (DI), LED317.1 (DO)
unnamed: LED316.1 (DO), LED325.3 (DI)
unnamed: LED317.3 (DI), LED318.1 (DO)
unnamed: LED318.3 (DI), LED319.1 (DO)
unnamed: LED319.3 (DI), LED320.1 (DO)
unnamed: LED321.3 (DI), LED322.1 (DO)
unnamed: LED322.3 (DI), LED323.1 (DO)
unnamed: LED323.3 (DI), LED324.1 (DO)
unnamed: LED324.3 (DI), LED325.1 (DO)
unnamed: LED326.1 (DO), LED327.3 (DI)
unnamed: LED327.1 (DO), LED328.3 (DI)
unnamed: LED328.1 (DO), LED329.3 (DI)
unnamed: LED329.1 (DO), LED330.3 (DI)
unnamed: LED330.1 (DO), LED331.3 (DI)
unnamed: LED331.1 (DO), LED332.3 (DI)
unnamed: LED332.1 (DO), LED333.3 (DI)
unnamed: LED333.1 (DO), LED334.3 (DI)
unnamed: LED334.1 (DO), LED335.3 (DI)
unnamed: LED335.1 (DO), LED336.3 (DI)
unnamed: LED336.1 (DO), LED337.3 (DI)
unnamed: LED337.1 (DO), LED338.3 (DI)
unnamed: LED338.1 (DO), LED339.3 (DI)
unnamed: LED339.1 (DO), LED340.3 (DI)
unnamed: LED340.1 (DO), LED341.3 (DI)
unnamed: LED341.1 (DO), LED342.3 (DI)
unnamed: LED342.1 (DO), LED343.3 (DI)
unnamed: LED343.1 (DO), LED344.3 (DI)
unnamed: LED344.1 (DO), LED345.3 (DI)
unnamed: LED345.1 (DO), LED346.3 (DI)
unnamed: LED346.1 (DO), LED347.3 (DI)
unnamed: LED347.1 (DO), LED348.3 (DI)
unnamed: LED348.1 (DO), LED349.3 (DI)
unnamed: LED349.1 (DO), LED350.3 (DI)
unnamed: LED351.1 (DO), LED352.3 (DI)
unnamed: LED352.1 (DO), LED353.3 (DI)
unnamed: LED353.1 (DO), LED354.3 (DI)
unnamed: LED354.1 (DO), LED355.3 (DI)
unnamed: LED355.1 (DO), LED356.3 (DI)
unnamed: LED356.1 (DO), LED357.3 (DI)
unnamed: LED357.1 (DO), LED358.3 (DI)
unnamed: LED358.1 (DO), LED359.3 (DI)
unnamed: LED359.1 (DO), LED360.3 (DI)
unnamed: LED360.1 (DO), LED361.3 (DI)
unnamed: LED361.1 (DO), LED362.3 (DI)
unnamed: LED362.1 (DO), LED363.3 (DI)
unnamed: LED363.1 (DO), LED364.3 (DI)
unnamed: LED364.1 (DO), LED365.3 (DI)
unnamed: LED365.1 (DO), LED366.3 (DI)
unnamed: LED366.1 (DO), LED367.3 (DI)
unnamed: LED367.1 (DO), LED368.3 (DI)
unnamed: LED368.1 (DO), LED369.3 (DI)
unnamed: LED369.1 (DO), LED370.3 (DI)
unnamed: LED370.1 (DO), LED371.3 (DI)
unnamed: LED371.1 (DO), LED372.3 (DI)
unnamed: LED372.1 (DO), LED373.3 (DI)
unnamed: LED373.1 (DO), LED374.3 (DI)
unnamed: LED374.1 (DO), LED375.3 (DI)
unnamed: LED376.1 (DO), LED377.3 (DI)
unnamed: LED377.1 (DO), LED378.3 (DI)
unnamed: LED378.1 (DO), LED379.3 (DI)
unnamed: LED379.1 (DO), LED380.3 (DI)
unnamed: LED380.1 (DO), LED381.3 (DI)
unnamed: LED381.1 (DO), LED382.3 (DI)
unnamed: LED382.1 (DO), LED383.3 (DI)
unnamed: LED383.1 (DO), LED384.3 (DI)
unnamed: LED384.1 (DO), LED385.3 (DI)
unnamed: LED385.1 (DO), LED386.3 (DI)
unnamed: LED386.1 (DO), LED387.3 (DI)
unnamed: LED387.1 (DO), LED388.3 (DI)
unnamed: LED388.1 (DO), LED389.3 (DI)
unnamed: LED389.1 (DO), LED390.3 (DI)
unnamed: LED390.1 (DO), LED391.3 (DI)
unnamed: LED391.1 (DO), LED392.3 (DI)
unnamed: LED392.1 (DO), LED393.3 (DI)
unnamed: LED393.1 (DO), LED394.3 (DI)
unnamed: LED394.1 (DO), LED395.3 (DI)
unnamed: LED395.1 (DO), LED396.3 (DI)
unnamed: LED396.1 (DO), LED397.3 (DI)
unnamed: LED397.1 (DO), LED398.3 (DI)
unnamed: LED398.1 (DO), LED399.3 (DI)
unnamed: LED399.1 (DO), LED400.3 (DI)
Q1: LED305.3 (DI); also elsewhere on the board
Q2: LED326.3 (DI); also elsewhere on the board
Q3: LED351.3 (DI); also elsewhere on the board
Q4: LED376.3 (DI); also elsewhere on the board

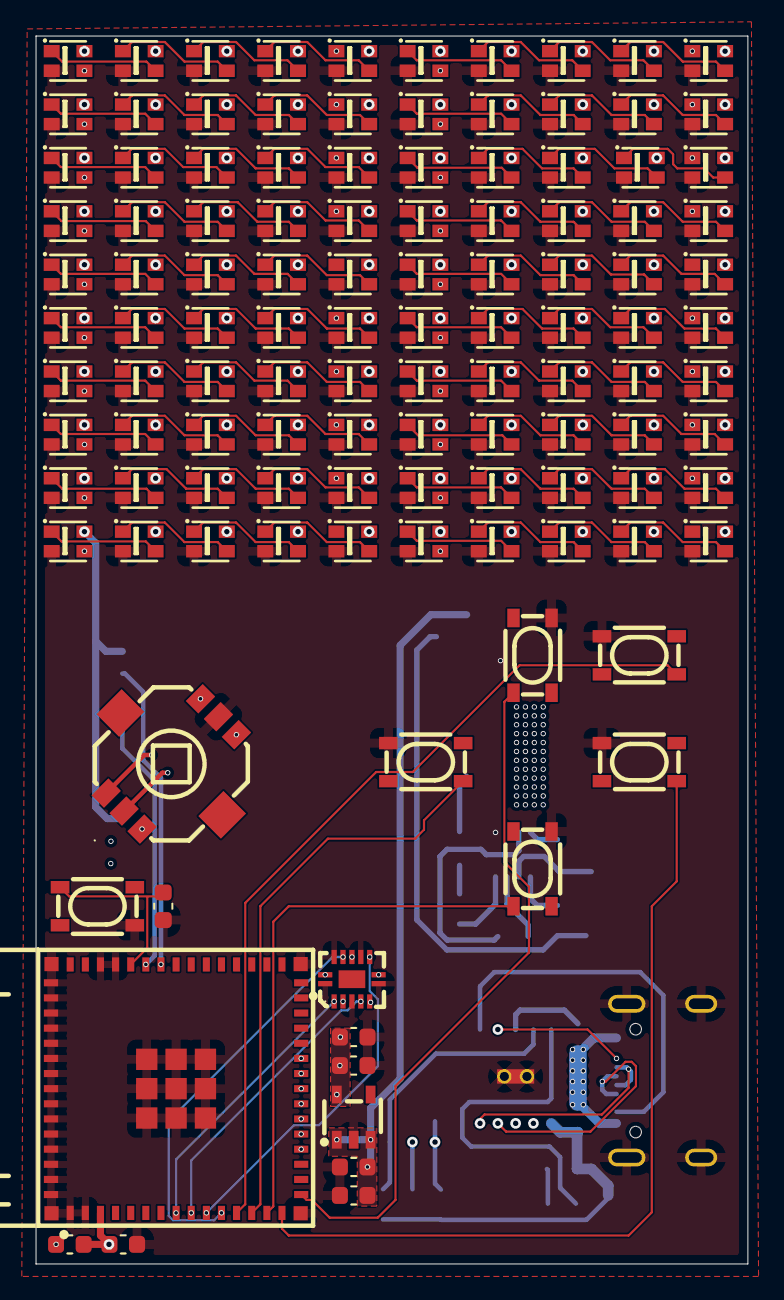
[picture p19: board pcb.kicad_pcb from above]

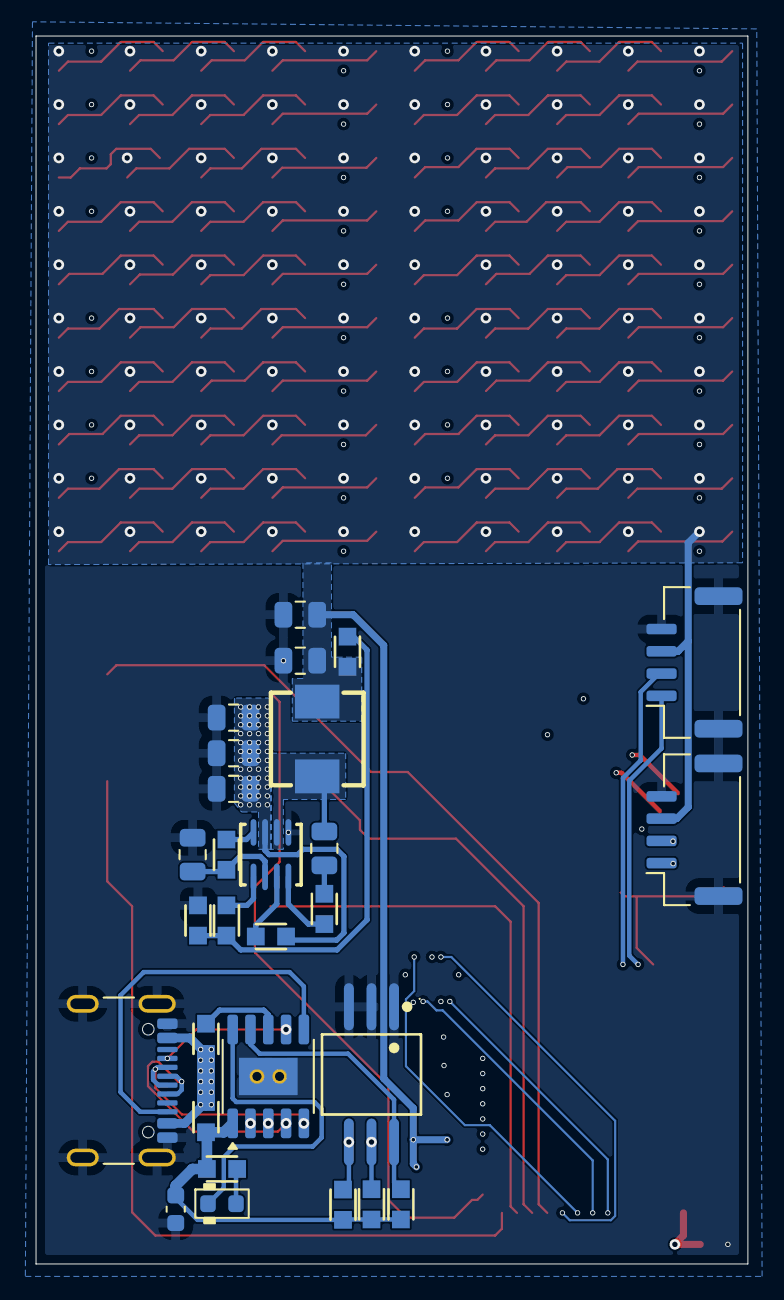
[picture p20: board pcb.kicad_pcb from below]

Board: 4 copper layers, 40.0 x 69.0 mm, 145 parts (28 on the bottom side), 142 nets.

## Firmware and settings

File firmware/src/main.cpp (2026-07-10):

#include <Arduino.h>
#include "engine.h"

void RunPCMode();
void RunSnake(int input);
void RunTetris(int input);
void RunScreensaver();

enum State {MENU, SNAKE, PC_MODE, TETRIS, SCREENSAVER};
State state = MENU;
int menuSelection = 0;

void setup() {
  Serial.begin(115200);
  Engine_Init();
}

void loop() {
    int input = ReadInputs();

    if (state != PC_MODE) {
        while (Serial.available()) {
            if (Serial.read() == OxFF) {
                delay(5);
                if (Serial.available() >= 4) {
                    uint8_t cmd = Serial.read();
                    uint8_t r = Serial.read();
                    uint8_t g = Serial.read();
                    uint8_t b = Serial.read();

                    if (cmd == 1) {
                        screensaverColor = CRGB(r, g, b);
                    }
                }
            }
        }
    }
    static unsigned long lastTelemetry = 0;
    if (millis() - lastTelemetry > 1000) {
        lastTelemetry = millis();
        if (state == MENU) Serial.println("State: MAIN MENU");
        else if (state == SNAKE) Serial.println("State: SNAKE");
        else if (state == PC_MODE) Serial.println("State: PC_MODE");
        else if (state == TETRIS) Serial.println("State: TETRIS");
        else if (state == SCREENSAVER) Serial.println("State: SCREENSAVER");
    }

    static unsigned long lastInteraction = 0;

    if (input != -1) {
        lastInteraction = millis();
        if (state == SCREENSAVER) {
            state = MENU;
            ClearScreen();
        }
    }

    if (millis() - lastInteraction > 10000 && state != PC_MODE && state != SCREENSAVER) {
        state = SCREENSAVER;
    }

    if (input == PIN_BTN_B) state = MENU;

    ClearScreen();

    if (state == MENU) {
        if (input == PIN_JOY_RIGHT) menuSelection = (menuSelection + 1) % 3;
        if (input == PIN_JOY_LEFT) menuSelection = (menuSelection - 1 < 0) ? 2 : menuSelection - 1;

        if (input == PIN_BTN_A) {
            if (menuSelection == 0) state = SNAKE;
            else if (menuSelection == 1) state = PC_MODE;
            else if (menuSelection == 2) state = TETRIS;
        }

        DrawPixel(4, 4, (menuSelection == 0) ? CRGB::Red : CRGB::DarkRed);
        DrawPixel(4, 5, (menuSelection == 1) ? CRGB::Blue : CRGB::DarkBlue);
        DrawPixel(4, 6, (menuSelection == 2) ? CRGB::Green : CRGB::DarkGreen);
    } else if (state == SNAKE) {
        RunSnake(input);
    } else if (state == PC_MODE) {
        RunPCMode();
    } else if (state == TETRIS) {
        RunTetris(input); 
    } else if (state == SCREENSAVER) {
        RunScreensaver();
    }

    ShowScreen();
    delay(16);
}

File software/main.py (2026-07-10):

import sys
import serial
import threading
import pyautogui
from PyQt5.QtWidgets import (QApplication, QWidget, QVBoxLayout, QHBoxLayout, QPushButton, QLabel, QGridLayout, QColorDialog, QCheckBox)
from PyQt5.QtCore import Qt, pyqtSignal, QObject

SERIAL_PORT = 'COM3'  
BAUD_RATE = 115200

class SerialListener(QObject):
    telemetry_received = pyqtSignal(str)

    def __init__(self, ser):
        super().__init__()
        self.ser = ser
        self.running = True
    
    def listen(self):
        while self.running and self.ser:
            if self.ser.in_waiting:
                try:
                    data = self.ser.readline().decode('utf-8').strip()
                    self.telemetry_received.emit(data)
                except:
                    pass

class CyberdeckStudio(QWidget):
    def __init__(self):
        super().__init__()
        self.setWindowTitle("Cyberdeck Studio")
        self.setFixedSize(700, 450)

        self.ser = None
        try:
            self.ser = serial.Serial(SERIAL_PORT, BAUD_RATE, timeout=1)
        except: 
            print(f"Warning: could not open{SERIAL_PORT}.")
        
        self.controller_mode = False
        self.initUI()
        self.start_serial_thread()
    
    def initUI(self):
        main_layout = QHBoxLayout()

        preview_layout = QGridLayout()
        preview_layout.setSpacing(10)
        self.pixels = [[(0, 0, 0) for _ in range(10)] for _ in range(10)]
        self.buttons = {}

        for y in range(10):
            for x in range(10):
                btn = QPushButton()
                btn.setFixedSize(35, 35)
                btn.setStyleSheet("background-color: black; border: 1px solid #333;")
                btn.clicked.connect(lambda checked, bx=x, by=y: self.paint_pixel(bx, by))
                preview_layout.addWidget(btn, y, x)
                self.buttons[(x, y)] = btn
        
        control_layout = QVBoxLayout()

        self.telemetry_label = QLabel("Telemetry: N/A")
        self.telemetry_label.setAlignment(Qt.AlignCenter)
        self.telemetry_label.setStyleSheet("font-size: 16px; font-weight: bold; color: #00FFFF; background-color: #222; padding: 10px;")

        self.color_btn = QPushButton("Select Color")
        self.color_btn.setFixedHeight(40)
        self.color_btn.setStyleSheet("background-color: #444; color: #FFF; font-size: 14px;")
        self.color_btn.clicked.connect(self.choose_color)

        self.gamepad_toggle = QCheckBox("Controller Mode")
        self.gamepad_toggle.setStyleSheet("color: #FFF; font-size: 14px;")
        self.gamepad_toggle.stateChanged.connect(self.toggle_gamepad)

        control_layout.addWidget(self.telemetry_label)
        control_layout.addSpacing(20)
        control_layout.addWidget(self.color_btn)
        control_layout.addSpacing(20)
        control_layout.addWidget(self.gamepad_toggle)
        control_layout.addStretch()

        main_layout.addLayout(preview_layout)
        main_layout.addSpacing(20)
        main_layout.addLayout(control_layout)

        self.setLayout(main_layout)
        self.setStyleSheet("background-color: #111;")

    def start_serial_thread(self):
        if self.ser:
            self.listener = SerialListener(self.ser)
            self.listener.telemetry_received.connect(self.handle_telemetry)

            self.thread = threading.Thread(target=self.listener.listen, daemon=True)
            self.thread.start()

    def paint_pixel(self, x, y):
        print(f"Painted {x}, {y}")
    
    def choose_color(self):
        color = QColorDialog.getColor()
        if color.isValid():
            self.selected_color = (color.red(), color.green(), color.blue())
            print(f"Selected color: {self.selected_color}")

    def toggle_gamepad(self, state):
        self.controller_mode = state == Qt.Checked
        print(f"Controller mode: {self.controller_mode}")

    def handle_telemetry(self, data):
        self.telemetry_label.setText(f"Telemetry: {data}")

if __name__ == "__main__":
    app = QApplication(sys.argv)
    window = CyberdeckStudio()
    window.show()
    sys.exit(app.exec_())

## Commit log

2026-07-10 basic pcb and stuff
    [mcu.kicad_sch, pcb.kicad_pcb, pcb.kicad_sch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]
2026-07-10 forgot journal
    [bom.csv, designators.csv, mcu.kicad_sch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]
2026-07-10 some stuff
    [bom.csv, designators.csv, positions.csv]
